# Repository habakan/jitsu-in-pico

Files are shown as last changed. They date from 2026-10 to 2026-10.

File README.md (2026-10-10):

# jitsu-in-pico

<sup>[日本語](docs/ja/README.md)</sup>

> **jitsu-in** — 実印, the seal that makes a signature binding in Japan; **pico** for the RP2350 it
> runs on.



`jitsu-in-pico` is the Raspberry Pi Pico 2 (RP2350) reference implementation for
[jitsu-in](https://github.com/habakan/jitsu-in). This repository contains the firmware, board-specific
UI and camera code, hardware documentation, and device integration checks. The reusable modules and
cross-platform examples live in jitsu-in.

Firmware stack: Pico 2 hardware, native firmware, WAMR, and jitsu-in modules

The [browser viewer](https://github.com/habakan/jitsu-in/tree/main/examples/viewer) is maintained in jitsu-in.

The device runs `parser.wasm` from jitsu-in. Its `Parser hash` screen shows the module's SHA-256;
`make check-repro` rebuilds the pinned artifacts and compares them with the recorded hashes.

| | |
|---|---|
| Modules, specifications, and cross-platform examples | [jitsu-in](https://github.com/habakan/jitsu-in) |
| Pico 2 hardware and wiring | [docs/hardware.md](docs/hardware.md), [docs/breadboard.md](docs/breadboard.md) |
| Parser ABI and host examples | [jitsu-in parser documentation](https://github.com/habakan/jitsu-in/tree/main/parser) |

Most design notes and measurements under `docs/` are in Japanese. English pages are linked from the
Japanese index at [docs/ja/README.md](docs/ja/README.md).

## Disclaimer

**This software has not been reviewed by a third party. Do not put real funds through it.**

It completes a signing round on signet. The measurements on this page come from this repository;
they do not show that anyone besides the author has tried to break it. Mainnet readiness, supported
transactions, and known limitations are listed in [docs/limitations.md](docs/limitations.md).

Found a security problem? [SECURITY.md](SECURITY.md) — **not** a public issue.

## The Pico 2 implementation

Read a seed from a SeedQR with the camera, receive a PSBT as an animated QR (UR), show it for review,
sign, and hand the signed PSBT back as a QR. The PC never holds a key or a recovery phrase — a
[signet transaction](https://mempool.space/signet/tx/de849e8c01a39fcf2aa84aaeeccb2ac8aea128086b2f4252539bcab90a0a432f)
went through that way ([verification procedure](docs/verification.md#signet-transaction)).

| Stage | Measured | |
|---|---|---|
| BIP39 seed (PBKDF2, 2048 rounds) | 0.47 s | native |
| PSBT parsing | 25 ms | **parser.wasm** (WAMR classic interpreter) |
| Checks and building the review screens | 147 ms | native |
| Signing (2 inputs, ECDSA + Schnorr) | 126 ms | native, cross-checked with embit |
| Animated QR output | 95 ms per part | reassembled byte-identical by `@ngraveio/bc-ur` |
| RAM | ~341KB of 520KB | quirc and the PSBT buffers share the heap |

Verified in this repository on RP2350 hardware, macOS hosts, and QEMU.

The firmware supports P2WPKH, P2TR key-path and P2WSH multisig of at most three keys (BIP48). BIP39
passphrase input is planned, but is not available yet.
PSBT v2 is not supported.

## Try it

### On hardware

Prebuilt firmware is on the [Releases](https://github.com/habakan/jitsu-in-pico/releases) page:
`jitsu-in-pico.uf2` for mainnet, `jitsu-in-pico-signet.uf2` for signet. Hold BOOTSEL while connecting
the Pico 2 over USB and copy the UF2 onto the drive. Building it yourself gives the same bytes
([docs/reproducible-build.md](docs/reproducible-build.md)).

Parts and wiring: [hardware](docs/hardware.md), [breadboard wiring](docs/breadboard.md). Japanese: [breadboard wiring](docs/ja/breadboard.md).

```sh
make deps-openocd                 # once, for SWD flashing (the Raspberry Pi fork of OpenOCD)
make run SECONDS=180              # flash, start listening, reset
make run TESTNET=1 SECONDS=180    # signet
```

Only a build with `TEST_SEED=1` can select the BIP39 test vector seed (the default is 0). Never put funds on it.
Known limitations and operational constraints are in [docs/limitations.md](docs/limitations.md).

## Check it yourself

```sh
make check-repro   # rebuild parser.wasm with a pinned toolchain and compare against the record
```

The device's `Parser hash` screen should match the parser hash produced by this build
([docs/reproducible-build.md](docs/reproducible-build.md)).

```sh
make check-core        # signing core vectors (71 checks)
make check-xpub        # account xpub and descriptor (official BIP84 vectors)
make check-psbt        # a full PSBT round, UR round-trip, signatures verified with embit
make check-ui          # screen construction
make check-seedqr      # SeedQR reading, with ASan
make check-qemu-psbt   # the same round on RV32, output compared with the host
make check-qemu-qr     # quirc instruction counts
make check-qr-mac      # quirc vs zxing-cpp on the same images
make check-camera-sim  # camera.pio against a Python simulator
make -C components/parts/parser test        # parser vectors (529 checks)
make -C components/parts/parser check-fuzz  # fuzzing the PSBT and UR parsers
```

Expected values come from independent implementations: embit, hashlib, `@ngraveio/bc-ur`, zxing-cpp,
Bitcoin Core. New tests are checked with mutation testing before they are trusted.

## What this repository contains

`src/` is the firmware that ships as the UF2; `bringup/` holds the other programs for the board.
Host and QEMU checks live under `tests/`.

| | | TCB |
|---|---|---|
| `components/parts/` | Pinned [jitsu-in](https://github.com/habakan/jitsu-in) submodule: reusable parser and signer modules. Their specifications and host examples are maintained in jitsu-in | **outside** |
| `components/qr/` | QR decoder ([quirc](https://github.com/habakan/quirc) submodule) | outside |
| `src/` | The firmware's entry point (`main.c`) and the pin assignment (`board_pins.h`) | inside |
| `src/drivers/` | Display (ST7789), buttons, camera (PIO + DMA). Runs only on the board | inside |
| `src/ui/` | Builds the 240x240 screens, independent of where they are shown | inside |
| `src/runtime/` | The call boundary into `parser.wasm` (every offset and length is range-checked) and the WAMR platform layer | inside |
| `bringup/` | Wiring checks and benchmarks: buttons, camera, PIO loopback, a PSBT round without UI | - |
| `tests/` | Host (`host/`), QEMU (`qemu/`) and screen (`ui/`) checks | - |
| `tools/` `docs/` | Build and verification tools, wiring diagrams, measurements, and implementation documentation |  - |

Dependencies (`third_party/`, gitignored) are cloned by `make deps`: libsecp256k1, WAMR 2.4.3,
pico-sdk 2.3.1, QR-Code-generator, the spleen font, and a RISC-V toolchain.

## Documentation

| If you want to... | Read |
|---|---|
| Understand how the device works | [System architecture](docs/architecture.md) |
| Review the parser boundary and signing path | [Signing architecture](docs/signing-architecture.md) |
| Check supported transactions and known risks | [Limitations](docs/limitations.md) |
| Rebuild and verify the published artifacts | [Reproducible build](docs/reproducible-build.md) |
| Repeat the signet transaction procedure | [Verification](docs/verification.md) |
| See performance and feasibility measurements | [Feasibility and performance](docs/feasibility.md) |
| Identify parts and wire the device | [Hardware](docs/hardware.md), [breadboard](docs/breadboard.md) |

## Contributing

Patches welcome: [CONTRIBUTING.md](CONTRIBUTING.md). Security problems go to
[SECURITY.md](SECURITY.md), never to a public issue.

## License

MIT ([LICENSE](LICENSE)). Third-party code is listed in [NOTICE](NOTICE).

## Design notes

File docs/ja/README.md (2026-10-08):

# jitsu-in-pico

<sup>[English](../../README.md)</sup>

> **jitsu-in ── 実印。** 署名に拘束力を与える印。**pico** は動作先の RP2350 から。



英語版は [README.md](../../README.md) です。

`jitsu-in-pico` は [jitsu-in](https://github.com/habakan/jitsu-in) の Raspberry Pi Pico 2（RP2350）参照実装です。
ファームウェア、基板固有の UI・カメラ処理、配線資料、実機連携の検証を置いています。
再利用モジュールと言語別の利用例は jitsu-in 側で管理しています。

## 安全上の注意

> **状態: 第三者のレビューを受けていません。本番の資金には使わないでください。**

signet で署名から送信まで一巡しました。ここに載せた数値はこのリポジトリで測ったものですが、
作者以外が攻撃を試みたことを示すものではありません。mainnet の前提や対応範囲は
[制約一覧](limitations.md)をご覧ください。

セキュリティ上の問題は [SECURITY.md](../../SECURITY.md)（英語）に従って報告してください。**公開 issue には書かないでください。**

ブラウザの [PSBT ビューア](https://github.com/habakan/jitsu-in/tree/main/examples/viewer) は jitsu-in 側で管理しています。

デバイスが使う `parser.wasm` は jitsu-in の成果物です。画面の `Parser hash` と
`make check-repro` の記録を突き合わせられます。

| | |
|---|---|
| モジュールの仕様と他環境での利用 | [jitsu-in](https://github.com/habakan/jitsu-in) |
| parser の ABI とホスト実装例 | [jitsu-in parser](https://github.com/habakan/jitsu-in/tree/main/parser)（英語） |

## Pico 2 の実装

カメラで SeedQR を読み、アニメーション QR（UR）で PSBT を受け取ります。画面で内容を確認して署名し、
署名済み PSBT を QR で返します。PC 側に鍵やシードフレーズを置かず、
[signet の取引](https://mempool.space/signet/tx/de849e8c01a39fcf2aa84aaeeccb2ac8aea128086b2f4252539bcab90a0a432f)
を送信しました（手順は [検証手順](../verification.md#signet-transaction)をご覧ください）。

| 段 | 実測 | |
|---|---|---|
| BIP39 シード（PBKDF2 2048 回） | 0.47 s | ネイティブ |
| PSBT 解析 | 25 ms | **parser.wasm**（WAMR classic interp） |
| 検査・確認画面の組み立て | 147 ms | ネイティブ |
| 署名（2 入力、ECDSA + Schnorr） | 126 ms | ネイティブ。embit で独立検証 |
| アニメーション QR 出力 | 1 パート 95 ms | `@ngraveio/bc-ur` で復元・バイト一致 |
| RAM | 約 341KB / 520KB | quirc と PSBT バッファはヒープを共有 |

このリポジトリでは、RP2350 実機、macOS のホスト、QEMU で確認しています。

## 利用方法

### 実機

ビルド済みのファームは [Releases](https://github.com/habakan/jitsu-in-pico/releases) にあります
（`jitsu-in-pico.uf2` が mainnet、`jitsu-in-pico-signet.uf2` が signet）。BOOTSEL を押しながら USB で
つなぎ、表示されたドライブに UF2 をコピーしてください。自分でビルドした場合も同じバイト列になります
（[再現可能ビルド](reproducible-build.md)をご覧ください）。

部品と論理的なピン割り当ては [hardware.md](../hardware.md)（英語）、実配線は [breadboard.md](breadboard.md)（日本語）をご覧ください。

```sh
make deps-openocd                 # 一度だけ。SWD 書き込み用（Raspberry Pi のフォーク）
make run SECONDS=180              # 書き込み → 受信開始 → リセット
make run TESTNET=1 SECONDS=180    # signet 用
```

`TEST_SEED=1` でビルドした場合だけ BIP39 のテストベクタを選べます（既定は 0）。このビルドでは資金を扱わないでください。
実機の運用上の制約は[制約一覧](limitations.md)をご覧ください。

## ビルドと検証

```sh
make check-repro   # 版を固定したツールチェーンで parser.wasm を作り直し、記録と突き合わせる
```

デバイスの `Parser hash` 画面と再現ビルドの結果が一致すれば、
**デバイス上の解析器が公開ソースからビルドされたこと**を確認できます
（[再現可能ビルド](reproducible-build.md)をご覧ください）。

```sh
make check-core        # 中核のベクタ（71 項目）
make check-xpub        # 口座 xpub とディスクリプタ（BIP84 の公式ベクタ）
make check-psbt        # PSBT 一巡 + UR の往復 + 署名を embit で独立検証
make check-ui          # 画面の組み立て
make check-seedqr      # SeedQR の読み取り（ASan 付き）
make check-qemu-psbt   # RV32 で PSBT 一巡（ホストの出力と一致するか）
make check-qemu-qr     # quirc の命令数
make check-qr-mac      # quirc と zxing-cpp の読取可否を比べる
make check-camera-sim  # camera.pio を Python のシミュレータで検証
make -C components/parts/parser test        # 解析器のベクタ（529 項目）
make -C components/parts/parser check-fuzz  # 解析器へのファジング
```

期待値は embit / hashlib / `@ngraveio/bc-ur` / zxing-cpp / Bitcoin Core で独立に作成しています。
テストを追加した場合は、ミューテーションテストで検出力を確かめています。

## 対応範囲

現在は単署名の P2WPKH / P2TR に対応しています。BIP39 パスフレーズ入力とマルチシグは今後対応予定ですが、現行ファームウェアでは使えません。マルチシグの方式は未定です。PSBT v2 には対応していません。詳しくは[制約一覧](limitations.md)をご覧ください。

## このリポジトリの内容

`src/` に UF2 として配布するファームウェア本体、`bringup/` にそれ以外の実機用プログラムがあります。
ホストと QEMU の検査は `tests/` にあります。

| | | TCB |
|---|---|---|
| `components/parts/` | [jitsu-in](https://github.com/habakan/jitsu-in) の固定 submodule。再利用する parser / signer モジュールを含む。仕様とホスト実装例の管理先は jitsu-in | **外** |
| `components/qr/` | QR デコーダ（submodule [quirc](https://github.com/habakan/quirc) の `mcu` ブランチ。FPU 無し向けに固定小数点化） | 外 |
| `src/` | ファームの入口（`main.c`）とピン割り当て（`board_pins.h`） | 内 |
| `src/drivers/` | 液晶（ST7789）、ボタン、カメラ（PIO + DMA）。実機でしか動かない | 内 |
| `src/ui/` | 240x240 の画面を組む。表示先に依存しない | 内 |
| `src/runtime/` | parser.wasm の呼び出し口（線形メモリとの出入りを範囲検証する境界）と WAMR のプラットフォーム層 | 内 |
| `bringup/` | 配線確認と計測。ボタン、カメラ、PIO ループバック、UI なしの PSBT 一巡 | - |
| `tests/` | ホスト（`host/`）、QEMU（`qemu/`）、画面（`ui/`）の検査 | - |
| `tools/` `docs/` | ビルド・検証ツール、配線図、この実装の設計と実測の記録 | - |

`third_party/`（gitignore 済み）の依存は `make deps` で clone します。libsecp256k1、WAMR 2.4.3、
pico-sdk 2.3.1、QR-Code-generator、spleen フォント、RISC-V ツールチェーンを取得します。

### 実機のファームの種類

| ターゲット | 用途 |
|---|---|
| `app` | 本体。PSBT 署名の一巡、xpub 表示、解析器ハッシュ表示 |
| `app_nolcd` | 同じ内容を UART に文字で出す（液晶なしでの回帰） |
| `psbt_bench` `qr_bench` | 時間・メモリの計測 |
| `camera_test` `pio_loopback_test` `button_test` | 配線とカメラの切り分け |

## 設計・検証資料

| 文書 | 内容 |
|---|---|
| [system architecture](../architecture.md)（英語） | 技術スタック・信頼境界・一巡・メモリ構成 |
| [signing architecture](../signing-architecture.md)（英語） | 現在の解析・署名構成と信頼境界 |
| [再現可能ビルド](reproducible-build.md) | ビルド成果物の再現方法 |
| [verification](../verification.md)（英語） | signet での送金とビルド・検証手順 |
| [Feasibility and performance measurements](../feasibility.md)（英語） | RP2350 のメモリ・速度、QR、BIP39 / BIP32、WASM / AOT の計測 |
| [hardware](../hardware.md)（英語）・[breadboard](../breadboard.md)（英語）・[breadboard](breadboard.md)（日本語） | 部品と配線、実配線図 |

計測条件と再現手順は [Feasibility and performance measurements](../feasibility.md)（英語）にまとめています。

## 外部プロジェクトへの貢献

- **WAMR**: classic interpreter の `i64.store` が 4 byte 境界を前提にしていた問題の修正を、固定した upstream commit に含めています
  （[PR #5123](https://github.com/wasm-micro-runtime/wasm-micro-runtime/pull/5123)、2026-09-30 マージ）。
  非整列アクセスを許さない CPU で発生し、QEMU では再現しません。
- **quirc**: 自前フォーク（`mcu` ブランチ）で固定小数点化と未マージのセキュリティ修正の取り込みを行い、
  UBSan とファジングを実施しています。

## 貢献

変更の送り方は [CONTRIBUTING.md](../../CONTRIBUTING.md)（英語）をご覧ください。セキュリティ上の問題は公開 issue ではなく、
[SECURITY.md](../../SECURITY.md)（英語）に従って報告してください。

## ライセンス

ライセンスは MIT です（[LICENSE](../../LICENSE)）。取り込んでいる第三者のコードは [NOTICE](../../NOTICE) をご覧ください。

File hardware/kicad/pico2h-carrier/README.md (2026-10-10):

# Pico 2 H carrier (KiCad draft)

現行の jitsu-in-pico 配線を、Pico 2 H・LCD・OV7675 のソケット接続へ移すための KiCad 下書きです。

## ファイル

- `pico2h_carrier.kicad_sch`: コネクタ単位の回路図。ネットラベルは既存の実配線に合わせています。
- `pico2h_carrier.kicad_pcb`: 58 x 38 mm・四隅1 mm面取りの外形、4つの固定穴、部品の機械領域。電気フットプリントは未配置です。
- `PicoCarrier.kicad_sym`: この設計用のコネクタシンボル。
- `sym-lib-table`: 上記シンボルライブラリのプロジェクト登録。

## コネクタ

| Ref | 対象 | フットプリント |
|---|---|---|
| J1 | Pico 2 H 左列、物理ピン1–20 | 1x20 2.54 mm female socket（B面） |
| J2 | Pico 2 H 右列、USB側から物理ピン40–21 | 1x20 2.54 mm female socket（B面） |
| J3 | M154-240240-RGB | 1x8 2.54 mm female socket |
| J4 | OV7675 / Arducam B0070 | 2x10 2.54 mm female socket（B面） |
| SW1, SW2 | 進む、承認 | 汎用6 mm THTタクトスイッチ |
| J5 | Debug Probe UART RX/GND | 1x2 2.54 mm female socket |

基板上の電気接続は回路図のネットラベルを参照してください。LCDのJ3 pin 1はGND、カメラJ4は奇数ピンが左列です。Pico右列J2 pin 1はUSB側のVBUS位置です。

## 仮レイアウト

前面（F面側）にLCDと右端の操作ボタン2個、キャリア基板の裏面（B面）にPico 2 H、背面ケースにカメラを置く積層構成です。基板の横幅はPicoの51 mm、縦幅はLCDの32 mmとカメラの30.5 mmに合わせて58 x 38 mmにしています。USB端子は左側へ向きます。LCDは前カバー、カメラは背面ケースに固定し、短いハーネスでJ3（F面）・J4（B面）へ接続します。

Rev Cの[完成・内部図](3dprint/assembly_preview.png)、[回転できる3Dビュー](3dprint/assembly.html)、[Bambu Studio用3MF・組立手順](3dprint/README.md)を用意しました。ケースは63.4 × 43.4 × 42.3 mmです。

PCB座標はケースXY座標から各2.7 mmを引いた値です。固定穴はPCB上で(3, 3)、(55, 3)、(3, 35)、(55, 35)、直径2.7 mmです。ケースを閉じるねじで、前カバー・キャリア・背面ケースを共締めします。寸法はケースと同じ寸法ファイルを使います。

`MECH_CASE`と`MECH_COMPONENTS`にそれぞれケース・電子部品の簡略VRMLを登録しています。KiCadの3Dビューで配置を参照し、内部を見たい場合は`MECH_CASE`のモデル表示を無効にしてください。VRMLの原点はPCB左上・表面です。電子部品のモデルは電気フットプリントと独立しているため、部品配置を変更した場合は参照モデルも更新します。

## 機械設計の前提

- Pico 2 H: 51 x 21 mm、ヘッダ間隔17.78 mm、2.54 mmピッチ。[Raspberry Piデータシート](https://datasheets.raspberrypi.com/pico/pico-2-datasheet.pdf)
- M154-240240-RGB: 公称基板外形43.72 x 32 mm。[秋月電子の製品ページ](https://akizukidenshi.com/catalog/g/g131019/)
- Arducam B0070: 公称基板外形30.5 x 30.5 mm、20ピン。[秋月電子の製品ページ](https://akizukidenshi.com/catalog/g/g113201/)
- TVDP01-G73BB: 6 x 6 mm、端子間ピッチ4.5 mm。[秋月電子の製品ページ](https://akizukidenshi.com/catalog/g/g109825)

公称外形と仮の実装高さに基づき、取付柱・押し子・USB開口を設けた調整用試作です。未計測のレンズ高さ、コネクタの向きと奥行き、ソケット高さは[寸法ファイル](3dprint/case_dimensions.json)に仮定を記録しています。実測後に確定してください。

## 次の作業

1. LCDとカメラの実物でヘッダ位置・固定穴・レンズ突出量を測り、基板上の配置を確定する。
2. A4に基板外形を1:1印刷し、部品とUSBケーブルの干渉を確認する。
3. KiCadでコネクタ位置と固定穴を配置し、ネットを同期して配線する。J1/J2/J4はB面配置でピン配列が反転する。
4. [3Dプリント用ケース試作](3dprint/README.md)を実物に合わせて調整し、基板を仮組みする。
5. ERC/DRCとケース寸法を確認してから製造データを出力する。

## 確認

この作業環境には KiCad がないため、KiCad上での読込確認、ERC、DRC、Gerber出力は未実施です。製造データとして発注する前にKiCadで開き、フットプリントを配置して確認してください。

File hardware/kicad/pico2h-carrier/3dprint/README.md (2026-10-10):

# Pico 2 H ケース Rev C — 調整用試作

外形 **63.4 × 43.4 × 42.3 mm**（ボタンを含む高さ43.3 mm）。キャリア基板は58 × 38 mmです。前面に液晶と操作ボタン、背面にカメラを置き、Picoはキャリア基板の裏面へ挿します。面積を小さくした代わりに部品を重ねたため、Rev Bの30.4 mmより厚くなっています。ユーザー了承のもと、未計測箇所は仮寸法で作成しています。

## 完成イメージ

- [完成・内部配置](assembly_preview.png)
- [分解図](assembly_exploded.png)
- [回して確認する3Dビュー](assembly.html)：ブラウザーで開き、「完成」「内部」「分解」を切り替えます。外部通信は不要です。
- [組立GLB](assembly.glb)：電子部品を含む閲覧用。印刷には下記の3MF/STLを使います。

画像・3Dビュー・STLは共通の形状データから生成しています。電子部品は外形を簡略化したモデルで、配線とねじ軸は省略しています。

## Bambu Studioで印刷するファイル

| ファイル | 内容 | 印刷方向 |
|---|---|---|
| [bambu_plate_01_base.3mf](bambu_plate_01_base.3mf) | 背面ケース1個（カメラ窓付き） | 外側底面がベッド |
| [bambu_plate_02_front.3mf](bambu_plate_02_front.3mf) | 前カバー1個 | 外側の画面側がベッド |
| [bambu_plate_03_small_parts.3mf](bambu_plate_03_small_parts.3mf) | カメラ裏押さえ1個、押し子2個 | 裏押さえは平置き、押し子は頭がベッド |

3MFは**mm単位の形状のみ**を含みます。3ファイルをそれぞれ別の印刷として開きます。プリンター・素材設定、サポート、G-codeは含みません。小物3個は間隔を空けて配置済みです。

プリンター本体のUSB/SDから印刷する場合、本体の一覧に出るのはスライス済みの`.gcode.3mf`だけです。この3MFをそのままコピーしても表示されません。

1. Bambu Studioで実機の機種・ノズル径を選択します。今回の想定はX2Dです。
2. 各3MFを開きます。選択肢が出た場合は形状の読み込みを選びます。
3. 倍率100%のままプレート中央に配置します。背面ケースが63.4 × 43.4 × 39.9 mmであることを確認します。
4. 素材未指定のため、最初の案はPLA・0.4 mmノズル・積層0.20 mm・壁4周・上下5層・インフィル20%です。温度とベッドは使用フィラメントのプリセットを使います。
5. 背面ケースのUSB穴上辺、押し子のつば下面はサポート対象です。プレビューで浮いた層がないか確認します。前カバーは固定柱が上向きです。外側ねじ座ぐりの橋渡しも確認してください。
6. プレートをスライスし、「プレートのスライスファイルをエクスポート」で`.gcode.3mf`を保存します。USB/SDへはこのファイルをコピーします。Bambu Studioの「印刷」から直接送ってもかまいません。
7. まず空のケースと押し子を仮組みしてから、部品を取り付けます。

X2Dの公式造形範囲（主ノズル256 × 256 × 260 mm）に収まる寸法です。[Bambu Lab公式仕様](https://blog.bambulab.com/xcellence-made-simple-bambu-lab-presents-the-x2d/)

個別STL：

- [背面ケース](pico2h_case_base.stl)
- [前カバー](pico2h_case_front.stl)
- [カメラ裏押さえ](pico2h_case_camera_retainer.stl)
- [次へ押し子](pico2h_case_button_1.stl)
- [承認押し子](pico2h_case_button_2.stl)

## どこに入るか

| 部品 | 固定・接続 |
|---|---|
| LCD M154-240240-RGB | 前面左。4つの基板穴を前カバーの柱へねじ留め。キャリア表面のJ3へ8芯ハーネス |
| 操作スイッチ2個 | キャリア表面の右端。前カバーの穴に通した押し子で操作 |
| キャリア基板 | 58 × 38 mm、四隅1 mm面取り。背面ケースの4本の柱と前カバーの柱で挟み、ケースねじで共締め |
| Pico 2 H | キャリア**裏面**の1×20ソケット2本に挿入。部品面は背面側。USBは左側の16 × 9.6 mm開口へ |
| カメラ B0070 | 背面ケースの内側。レンズを背面のØ18 mm窓へ向け、四隅の受けと裏押さえで挟んで4本のねじで固定。キャリア裏面のJ4へ20芯ハーネス。カメラ側は2×10ピンソケット（高さ8.5 mm）に短い線を付けたもの |

Picoを裏面に挿すため、KiCadではJ1/J2をB面に配置し、ピン配列が左右反転することに注意します。BOOTSELはキャリア基板を外して操作します。ブレッドボードをそのまま収納する設計ではなく、キャリア基板へ移設する前提です。

## ねじ・組立

ねじは樹脂へねじ込む試作想定です。長さは頭を除く値で、下穴径とねじ形状は試し刷りで合わせます。

| 用途 | 候補 | 数 | モデルの下穴 |
|---|---|---|---|
| ケース開閉・キャリア固定 | 呼び径2.5 × 25 mm、樹脂用タッピングねじ | 4 | Ø2.0、深さ10 mm（背面ケース側） |
| LCD固定 | M1.6 × 5 mm | 4 | Ø1.3、盲穴 |
| カメラ裏押さえ | M2 × 8 mm | 4 | Ø1.6、盲穴 |

LCD穴はØ2.0 mmなので、M2.5は使いません。LCD固定ねじは裏面から挿します。小ねじを樹脂へ直接使う箇所は、必要に応じて下穴の径・深さを調整してください。強く締め込むと柱が割れるため、基板が動かなくなる程度で止めます。

1. キャリア基板の表面にJ3・J5・スイッチ、裏面にPico用ソケットとJ4を取り付け、配線を完成させます。表面のはんだ側リードはPicoのヘッダ側へ出るため、短く切りそろえます。
2. カメラを背面ケースの四隅の受けへ置き、裏押さえをねじ留めします。カメラのハーネスを先に挿しておきます。
3. キャリア裏面へPicoを挿し、カメラのハーネスをJ4へつないでから、キャリアを背面ケースの4本の柱へ載せます。
4. 前カバーを裏返し、押し子2個を穴へ入れます。押し子は完成時にスイッチとの隙間0.2 mmを想定しています。
5. LCDを4本の柱へ固定します。ガラスと前カバーは0.3 mm離す想定です。LCDのハーネスをJ3へつなぎます。
6. 前カバーを載せ、4本のねじで前カバー・キャリア・背面ケースをまとめて固定します。
7. USBケーブルが挿せること、ボタンが戻ること、配線を挟まないことを確認します。

## 仮寸法の調整

[case_dimensions.json](case_dimensions.json)を編集して再生成します。XY座標はキャリア基板（KiCad）の座標で、ケース座標は各2.7 mm足した値です。高さ方向は背面からカメラ、Pico、キャリア、LCDの順に積み上げて自動計算します。「調整可能」は主にCAD寸法の変更・再印刷を意味し、完成品にスライド調整機構はありません。

| パラメータ | 現在値 | 実物で確認する箇所 |
|---|---|---|
| `camera.lens_height` | 3 mm（写真から2〜3 mmと推定） | **基板表面から**レンズ先端まで。裏面から測った値なら基板厚を引く |
| `camera.pcb_thickness` | 1.6 mm | カメラ基板厚 |
| `camera.lens_offset` | [15.25, 15.25] mm | 基板左上からレンズ中心 |
| `camera.rear_connector_depth` | 11 mm | 基板裏面から接続済みヘッダ・コネクタの最下面。2×10ピンソケットの短いハーネス前提。ジャンパーワイヤのメス端子は約16.5 mm＋曲げ代が要り収まらない |
| `lcd.active_origin` | [7.11, 2.14] mm | 横向き基板の左上から表示域左上。図面の向きは実物照合待ち |
| `lcd.rear_connector_depth` | 11.3 mm | LCD裏側の接続済みコネクタ |
| `pico.socket_height` / `header_height` | 8.5 / 2.5 mm | キャリア裏面からPicoまで合計11 mm |
| `pico.component_gap` | 2 mm | カメラ裏押さえとPico部品面の間隔 |
| `buttons.switch_height` | 7.3 mm | キャップを外したスイッチ上端。実物照合待ち |
| `case.fit_clearance` | 片側0.3 mm | ケースのはめ合い |

レンズ高さ・コネクタ深さを変更すると、ケースの厚みと各柱の高さも変わります。大きく変更した場合は周辺部品との干渉チェックが失敗することがあります。ヘッダの向き・XY位置、取付面、ねじ径は必要に応じて`build_case_stl.py`で変更します。ケース全体の大きな変更には配線コネクタ等の固定座標も見直してください。

カメラは四隅1.2 mm角の受けに載り、裏押さえは左右の辺1.2 mm幅を押さえます。ヘッダは上辺にあると仮定し、上辺は押さえません。その場所に部品がないか確認します。ハーネスの曲げ余裕・はんだ面・光学的な視野角はモデルに含まれていません。Ø18 mmのカメラ窓は仮値です。

## 再生成

Python 3.11の仮想環境で、リポジトリ直下から実行します。

```sh
uv venv -p 3.11 /tmp/pico-case-venv
VIRTUAL_ENV=/tmp/pico-case-venv uv pip install -r hardware/kicad/pico2h-carrier/3dprint/requirements.txt
/tmp/pico-case-venv/bin/python hardware/kicad/pico2h-carrier/3dprint/build_case_stl.py
```

STL、3MF、OpenSCAD、GLB、KiCad参照用VRML、画像、HTML、検査レポートを出力します。OpenSCADは生成結果で、寸法変更はJSON/Pythonが正本です。`part`に`base`、`lid`、`camera_retainer`、`button_1`、`button_2`を指定すると印刷向きで表示します。

KiCadの機械配置を更新する場合だけ、次を別途実行します。電気フットプリント・配線があるPCBへの自動上書きは拒否します。

```sh
/tmp/pico-case-venv/bin/python hardware/kicad/pico2h-carrier/3dprint/update_mechanical_layout.py
```

日本語画像にはmacOSのHiragino Sans GBを使用します。他のOSでは`render_case.py`の`FONT`を日本語フォントへ変更してください。

## 確認結果と残作業

- 全24パーツのメッシュについて、閉じた形状・面の向き・正の体積を確認。
- 印刷する5パーツは各1つの連結した立体。STLと3MFを再読込して形状を確認。
- 仮寸法で253組の部品の体積干渉を計算し、重なり0件。ねじ頭は対象外。[fit_report.json](fit_report.json)
- Bambu Studio 02.08.02.61の`--info`で3つの3MFを読み込み、5パーツすべて`manifold = yes`、公称寸法を確認。[読込ログ](bambu_import_check.txt)。スライス・実機印刷は未実施。
- 完成図と分解図は画像で確認。HTMLはJavaScriptの構文確認までで、ブラウザー上の操作確認は未実施。
- KiCadは固定穴・外形・機械領域・3D参照を更新済み。**電気フットプリント配置・配線・ERC/DRCは未完了**。KiCad本体がないためネイティブ読込は未確認です。

寸法根拠：[Pico 2](https://datasheets.raspberrypi.com/pico/pico-2-datasheet.pdf)、[LCD図面](https://akizukidenshi.com/goodsaffix/M154-240240-RGB-8.pdf)、[B0070製品情報](https://akizukidenshi.com/catalog/g/g113201/)、[スイッチ図面](https://akizukidenshi.com/goodsaffix/TVDP01-G73BB.pdf)。レンズ・コネクタ等の仮定はJSONと検査レポートにも記録しています。

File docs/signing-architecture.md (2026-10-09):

# Signing architecture: isolate parsing in WASM, keep keys and signing native

This is the current implementation. `parser.wasm` handles UR reassembly and PSBT parsing without
access to keys. Native code validates the fixed-size `Plan`, derives and checks keys, builds the
review screens, and signs. QR image decoding also runs natively and remains in the trusted computing
base.

## 1. The point

Keep the key outside the module that parses untrusted transaction data. If `parser.wasm` is
compromised, it cannot read the key from its linear memory.

## 2. What this defends against, and what it does not

| attack | current design |
|---|---|
| a crafted PSBT or UR takes over the parser and reads the key | defended. The key never enters the WASM linear memory |
| a compromised parser shows A on screen and signs B | defended. What is displayed and what goes into the sighash are built natively from the same struct (§5) |
| a compromised parser honestly displays a transaction the user should not accept | not defended. That is what the user's confirmation is for |
| a compromised parser corrupts the output PSBT | not defended. A signature commits to the transaction, so a corrupted PSBT is merely invalid — denial of service |
| the QR decoder (quirc) is taken over | not defended. quirc stays native and stays in the TCB (§7) |
| the SeedQR parser is taken over | out of scope, because that parser is not in WASM (§4) |

## 3. The shape of it

```
Camera ─> quirc (native) ─> QR payload bytes
                                 │
                                 ▼
             ┌──────── parser.wasm (no keys) ───────┐
             │ UR / BBQr reassembly, CBOR, PSBT     │
             │ parsing, then a fixed-length Plan    │
             └───────────────┬──────────────────────┘
                             │ the host copies the plan and non_witness_utxo, with checks
                             ▼
             ┌──────── signing core (native) ───────┐
             │ check the Plan, derive keys, confirm  │
             │ ownership, build the display, sighash,│
             │ sign                                  │
             └───────────────┬──────────────────────┘
                             │ the host writes back the signatures (plan_sig_t)
                             ▼
             parser.wasm: insert partial_sig into the original PSBT and serialize
                             │
                             ▼
                     qrcodegen (native) ─> LCD
```

parser.wasm has no imports at all. Everything crosses through buffers it exports, which the host reads
and writes. The host checks every address and length it returns against the bounds of the linear memory
with `wasm_runtime_validate_app_addr` before copying anything.

## 4. Who does what

| what | where | why |
|---|---|---|
| decoding the QR image (quirc) | native | over ten seconds per frame in WASM ([QR feasibility measurements](feasibility.md#qr-decoding-on-the-rp2350)) |
| UR / BBQr reassembly, CBOR, PSBT parsing | parser.wasm | the most complex parsing of untrusted input, and light because no crypto is involved |
| parsing a SeedQR or typed words | native | the input is the secret itself, so putting it in WASM would defeat the isolation |
| checking the Plan, deriving keys, confirming ownership, sighash, signing | native | it touches keys |
| building address strings (bech32 / base58) | native | the Plan carries only the scriptPubKey's bytes, so the parser cannot fake a string |
| the wording and numbers on the review screens | native | so that what is shown and what is signed come from the same struct |
| serializing the signed PSBT | parser.wasm | a signature commits to the transaction, so a compromise here cannot forge anything |

## 5. The core invariant

**What is displayed and what goes into the sighash are built natively, from the same `plan_t`.**
If parser.wasm emits a Plan that differs from the original PSBT, then that Plan is what the user sees
and that Plan is what gets signed. The native side does not need to establish that the Plan is faithful
to the PSBT. It only establishes two things:

1. that the Plan is internally consistent (§6)
2. that nothing bad happens if a value the user is not shown, such as an input amount, is a lie
   (§6, items 4 and 5)

## 6. What the native side checks

1. **Form:** record counts and lengths within their limits, unused fields zero, no reserved values.
   Nothing variable-length is parsed
2. **Inputs to be signed:** derive the key at the path the Plan gives and confirm the public key
   produces `witness_utxo.scriptPubKey` — `0014 || HASH160(pub)` for P2WPKH, the x-only key after the
   BIP86 tweak for P2TR. An input that does not match is not signed
3. **Deciding what is change:** an output's `key` is treated as a hint only. The native side re-derives
   the script on the same account's change chain (`.../1/i`, with a limit on `i`) and only calls it
   change when it matches
4. **The fee:** total input minus total output, computed natively. Overflow and negative values are
   refused
5. **Guarding against a lie about an input's amount:**
   - Taproot (BIP341) commits the sighash to every input's amount and scriptPubKey, so a signature made
     with a false amount is simply invalid
   - SegWit v0 (BIP143) commits only to the amount of the input being signed. That is what makes the
     2020 fee attack work: get the same input signed twice with different amounts. The countermeasure
     is to require `non_witness_utxo` in the multi-input case (§8, item 1)
6. **sighash type:** only `SIGHASH_ALL` and Taproot's `SIGHASH_DEFAULT` are accepted; all other types
   are rejected
7. **Network:** mainnet or testnet is decided by the native configuration, not by the Plan

## 7. What risk remains

- **quirc remains a parser of untrusted input inside the TCB.** It is fuzzed, but remains part of the
  trusted computing base because decoding in WASM is too slow
- **The code that reads the Plan also reads untrusted input natively.** Restricted to fixed-length
  records and kept to around a hundred lines
- **An input that makes parser.wasm run indefinitely.** WAMR runs without an instruction limit, so the
  call can block the UI until the device is reset
- **A vulnerability in WAMR itself.** If the linear memory's bounds checks can be broken, the isolation
  no longer holds. The WAMR interpreter remains part of the TCB

## 8. Current transaction support and constraints

1. **`non_witness_utxo` for SegWit v0 inputs:** required for every input when a SegWit v0 input is to
   be signed and there are two or more inputs. With a single input it is unnecessary, since a signature
   made with a false amount is merely invalid. The minimal native tx parser
   (`components/parts/parser/src/tx.c`, shared with jitsu-in) checks the txid, vout, amount and script
2. **First targets:** P2WPKH (BIP84) and P2TR (BIP86, no script tree)
3. **parser.wasm runtime:** the interpreter. Measured on RV32: 2.7M instructions
   to parse a PSBT and 40k to insert the signatures (§10), which is plenty
4. **Multisig:** not implemented. Script formats and nonce handling remain undecided.

## 9. Plan layout

The C struct is shared as is, with its size and offsets nailed down by `_Static_assert`. wasm32 and
rv32 are both little-endian ILP32, so the layout agrees. The native side copies it once, then checks it.

```c
#define PLAN_MAX_INPUTS  16
#define PLAN_MAX_OUTPUTS 16
#define PLAN_MAX_SPK     83   /* the standard OP_RETURN limit; P2TR and P2WSH need 34 */
#define PLAN_MAX_DEPTH   8

typedef struct {
    uint8_t  len;
    uint8_t  bytes[PLAN_MAX_SPK];
} plan_script_t;

typedef struct {
    uint8_t  depth;
    uint32_t fingerprint;
    uint32_t path[PLAN_MAX_DEPTH];
} plan_keypath_t;

typedef struct {
    uint8_t  prev_txid[32];
    uint32_t prev_vout;
    uint32_t sequence;
    uint64_t amount;            /* witness_utxo */
    plan_script_t spk;          /* witness_utxo */
    plan_keypath_t key;         /* depth = 0 for an input we will not sign */
    uint8_t  sighash_type;
} plan_input_t;

typedef struct {
    uint64_t amount;
    plan_script_t spk;
    plan_keypath_t key;         /* a change candidate; the native side re-derives to confirm */
} plan_output_t;

typedef struct {
    uint32_t magic, version;
    int32_t  tx_version;
    uint32_t locktime;
    uint8_t  n_inputs, n_outputs;
    plan_input_t  inputs[PLAN_MAX_INPUTS];
    plan_output_t outputs[PLAN_MAX_OUTPUTS];
} plan_t;
```

- The settled version is `components/parts/parser/include/plan.h`, on the jitsu-in side, with
  `_Static_assert` fixing the size and the offsets
- At 16 inputs and 16 outputs it is 5,016 bytes: 176 per input, 136 per output. Barely a dent in RAM
- These limits are part of the current parser ABI.
- `non_witness_utxo` crosses in a buffer of its own rather than in the Plan, with the same limit as the
  whole PSBT

## 10. Current implementation

The native core is implemented in `components/parts/signer/` (`make check-core`, `make check-qemu-core`).

| file | what it holds |
|---|---|
| `components/parts/signer/core.c` | the checks from §6 (`core_review`), the display model (`core_display`) and signing (`core_sign`). It records the SHA-256 of the reviewed plan and refuses to display or sign anything that does not match |
| `components/parts/signer/address.c` | addresses from a scriptPubKey: base58check for P2PKH and P2SH, bech32 for witness v0, bech32m for v1-v16. Nothing is produced for a non-standard script |
| `components/parts/signer/sighash.c` | BIP143 (P2WPKH, SIGHASH_ALL) and BIP341 key path, all seven hash types |
| `components/parts/parser/src/tx.c` | the minimal tx parser, shared with jitsu-in. Refuses non-minimal varints and trailing bytes; the txid is computed without the witness |
| `components/parts/signer/bip32.c` | BIP32 derivation |
| `components/parts/parser/src/sha256.c`, `components/parts/signer/ripemd160.c`, `sha512.c` | the hashes. Secrets are cleared through `components/parts/signer/wipe.h`, via a volatile pointer, so the optimiser cannot remove it |

What `core_review` actually does, making §6 concrete:

- An input that does not claim our fingerprint is not signed; its amount is used only for the fee. One
  that does claim it, but whose key does not produce its script, rejects the whole plan
- sighash types: `ALL` only for P2WPKH, `DEFAULT` and `ALL` only for P2TR
- An output counts as ours at `m/84'|86' / coin' / account' / {0|1} / i` — coin from the network
  setting, `i < 100000` — on the same account as the inputs being signed, and only when the script
  matches. Chain 1 is change, chain 0 is a self-transfer, which is what SeedSigner confirms as such.
  Anything else is external
- Every string on the review screens is built natively from the plan's bytes. A script that has no
  address is shown as the data for an OP_RETURN, or as the whole script in hex otherwise. The amount
  spent (`spend`) is the total of the external outputs

Tests: 71 checks, passing on both the Mac and RV32:

- BIP143's P2WPKH example: the sighash and the RFC6979 signature (DER) match the document
- The seven key-path cases from BIP341's wallet test vectors: sighash and Schnorr signature match, for
  every hash type
- BIP84 and BIP86: with the key derived from `abandon ... about`, review and signing pass and the
  signature verifies. The expected scripts are computed independently with embit and cross-checked
  against the values in BIP86 (`tools/generate/gen_core_vectors.py`)
- Addresses: BIP350's eight valid vectors; that invalid program lengths (1 and 41 bytes, and 16 and 21
  at v0) produce nothing; base58check, with embit for the expected values; the known addresses from
  BIP84 and BIP86
- Attack scenarios: swapping the plan after review, for both display and sign; fake change; a
  self-transfer; the index limit; change on another account; a key that does not match its script; a
  sighash type we do not allow; a non-zero unused field; outputs exceeding inputs; and the fee attack
  with no previous transaction, with a false amount, with the wrong vout and with the wrong txid
- Five deliberate breakages — BIP143's hash type, BIP341's spend_type, the fee-attack check, bech32m's
  constant, base58's leading zeros — were each confirmed to make a test fail

### parser.wasm (`components/parts/parser/src/psbt.c`, the [jitsu-in](https://github.com/habakan/jitsu-in) submodule)

- Turns a PSBT v0 (BIP174) into a `plan_t`, and inserts the natively produced signatures just before
  the end of each input map, leaving every other byte as it was
- The `.wasm` is 15,570 bytes and has no imports. It holds the input and output buffers
  (`PSBT_MAX` 32KB), so the linear memory is two pages
- Fields it interprets are checked strictly: duplicate keys, key and value lengths per type,
  v2-only fields, scriptSig and witness in the unsigned tx, the `non_witness_utxo`'s txid against
  `witness_utxo`, and trailing bytes
- Fields it does not interpret, MuSig2's among them, pass through untouched. It does not check whether
  a public key is on the curve, because the native side never uses the PSBT's public keys — it derives
  its own
- The only candidates for our keys are derivations matching the master fingerprint the host supplied,
  which is not a secret. Inputs already finalized or signed, and P2TR with a script tree, are not signed
- ECDSA uses the same low-R grinding as Bitcoin Core (`components/parts/signer/core.c`), so the signatures
  match embit's byte for byte

Verification (`make check-psbt`, `make check-qemu-psbt`):

- Six PSBTs built with embit for our own seed — P2WPKH with one and two inputs, P2TR with two, a mix,
  one including someone else's input, and two inputs with no `non_witness_utxo` — go through a full
  round, and the signed PSBT is verified independently with embit (`tests/host/check_signed_psbt.py`). The
  ECDSA signatures match embit's own byte for byte, and the Schnorr ones verify against embit's BIP341
  sighash. The two-input case with no `non_witness_utxo` is refused with `CORE_ERR_PREVTX_MISSING`
- Against Bitcoin Core's `test/functional/data/rpc_psbt.json` — 84 invalid and 48 valid, two of which
  have corrupt base64 and are excluded — there are no traps. Every invalid one is refused except the 15
  with MuSig2 fields. Of the valid ones 31 are accepted; the 14 PSBT v2 cases, two with no utxo and one
  with no inputs are refused (`make check-parser` in jitsu-in, `make check-parser` here)
- A full round on a mixed PSBT under RV32 (QEMU): parse 2.72M, review 17.1M, sign 14.5M, finalize 0.04M
  instructions. The signed PSBT is byte-identical between the Mac and RV32

### Bitcoin Core as the oracle (2026-10-04)

Core has no WASM target. Its PSBT code does compile to wasm32, though — measured, not assumed, with
our pinned wasi-sdk 34 (2026-10-04):

| | code | data | total | imports |
|---|---:|---:|---:|---:|
| `parser.wasm` | 13,562 | 1,369 | 15,570 | **0** |
| C++ with no STL and no exceptions | 7,658 | 0 | 8,022 | 3 |
| the same plus `string`, `vector`, `map` | 21,343 | 2,459 | 24,316 | 4 |
| `psbt.cpp` and 17 files of its closure | 103,219 | 9,746 | 114,549 | 17 |

Stripped and `wasm-opt -Oz`'d, it is 114,549 bytes, about 7x ours — not the 2.8 MB an unstripped link
reports, 93% of which is debug info. Where the difference comes from: a C++ floor of 7.7KB for
wasi-libc's startup and malloc, 13.7KB more for the STL templates and their allocator, and the rest
Core's own breadth — every script type, finalize, combine, miniscript, against our P2WPKH and P2TR key
path. Template instantiation in `serialize.h`, dynamic allocation and per-function unwind tables are
what grow it; our 13.5KB is barely above the bare C++ floor because there is none of that.

Two things still rule it out.

**Core's script code requires C++ exceptions**, and they do not link. `-fno-exceptions` fails to
compile (`script/script.h:248: cannot use 'throw' with exceptions disabled`), and with them enabled
wasi-sdk 34's prebuilt `libc++abi.a` leaves `_Unwind_RaiseException` and `__cpp_exception` undefined.
The 114,549-byte figure above only links because `--allow-undefined` turns those into imports, so it
is a module that would not run. Closing it means building libc++ from source, which gives up the
pinned official tarball the reproducible build rests on. In wasm, exceptions also mean the
exception-handling proposal, which is not one of Lime1's seven features, so the link-time gate rejects
it anyway — exactly what that gate is for. Clang 23 emits the new form (`try_table`, `exnref`) while
our pinned WAMR implements the old one (`TRY`, `CATCH`, `DELEGATE`), so the two do not even meet.

**On the device it does not fit regardless.** The classic interpreter rewrites bytecode as it loads,
so the module has to sit in writable RAM, and the RP2350 has 520KB in total for everything.

So this could run in a browser, where none of that binds, but never on the device. Patching out the
throws would change the picture — and would mean forking Core, at which point "verifiably the same
code as Core" is the thing that has been lost.

What we do take from Core verbatim is the part where being identical matters most —
**libsecp256k1, pinned to a commit**. Everything else is ours: PSBT parsing, sighash, BIP32, base58
and bech32, the hashes.

So rather than sharing Core's code, we require Core's answers (`make check-core-diff`).

| what is compared | how |
|---|---|
| the parse | `decodepsbt` against the `plan_t` parser.wasm built: version, locktime, and every txid, vout, sequence, amount, scriptPubKey, derivation path and master fingerprint |
| the fee | `decodepsbt`'s fee against `core_review`'s |
| **the signatures** | `walletprocesspsbt`'s against ours, **byte for byte** |

The third is only possible because both sides are deterministic: Core and this signer both grind for a
low R in ECDSA, and both pass a zero `aux_rand` for Schnorr. The same key over the same PSBT therefore
has exactly one right answer, and Core's is the authoritative one.

Measured: **39 PSBTs agree on the parse** — Core's own `rpc_psbt.json` valid cases plus our vectors —
and **8 signatures across 5 PSBTs are byte-identical**, ECDSA and Schnorr alike. Deliberately breaking
the low-R grinding makes two of them differ and the target fail. Notably one case still matched by
chance, because its first attempt already had a low R, so a single test case would have missed it.

Two things this does **not** claim. It does not show we share code with Core; it shows we give the same
answers, which is the part a user actually depends on. And `decodepsbt` describes what is in the file
while `plan_t` is an instruction to the signer, so the two are not the same kind of object: an input we
will not sign carries `sighash_type = 0` whatever the file says, and `core_review` rejects a plan that
breaks that (`core.c:93`). The comparison only requires agreement where both describe the same thing.

### Reassembling a UR, the animated QR

UR (BCR-2020-005) reassembly went into parser.wasm (in jitsu-in). Reassembling a fountain code is
also processing of untrusted input, so it belongs inside the sandbox.

- `parser_ur_reset`, `parser_ur_receive(len)`, `parser_ur_progress`. On completion the PSBT sits in the
  input buffer, ready for `parser_parse`. The accepted types are `crypto-psbt` and `psbt`
- The Xoshiro256**, the alias sampler and the shuffle that decide which fragments were mixed all match
  the expected values in Blockchain Commons' bc-ur tests: 1,148 checks, run natively under ASan and
  UBSan. Dropping one part and feeding the rest in reverse completes at the same 16 parts as the
  reference decoder, @ngraveio/bc-ur 1.1.13
- URs of our own PSBTs made with the reference encoder (`crypto-psbt` and `psbt`, fragments of 60, 150
  and 5000 bytes), fed in with one pure part in three dropped, come back as the original PSBT
- RV32 (QEMU): a mixed PSBT across 19 parts of 60-byte fragments costs 22.16M instructions in total and
  at most 4.23M for one part, which is 30 to 40ms at 150MHz. Signing the reassembled PSBT gives bytes
  identical to signing the binary one
- The `.wasm` reached 14KB, still with no imports. The linear memory in use (`__heap_base`) grew from
  88KB to 158KB, then came back to 132KB by removing the working arrays for the sampling and the
  shuffle. The order of computation did not change, so agreement with the reference still holds. WAMR's
  pool peaks at 147KB under QEMU, and the device application gives it 160KB

### Handing the signed PSBT back as an animated QR

- Encoding to a UR also lives in parser.wasm (`parser_ur_encode_start`, `parser_ur_encode_next`). It is
  formatting output for an untrusted wallet, so it has no bearing on the safety of the signature and can
  sit outside the TCB. Part for part it matches the reference encoder, @ngraveio/bc-ur, and it matches
  bc-ur's examples character for character (tested in jitsu-in)
- One part is 120 bytes, about 300 characters, which lands around QR v8, shown on the 240 px LCD at
  4 px per module (`ui_qr_render_line`, with a four-module quiet zone). Mixed parts keep coming after
  the pure ones, so a wallet that misses one can still reassemble
- Verification: reading the signed PSBT's UR back gives identical bytes, and rendering the LCD's QR
  screen to an image and reading it with zxing-cpp gives the part's string (`make check-psbt`)
- On the hardware (2026-10-01): a phone's QR reader reads the animated QR off the LCD. At 100 bytes per
  part it fits QR v8, 49 modules, which is 4 px per module on a 240 px LCD. At 120 bytes it became v9,
  the scale dropped to 3 px, and it would not read — so **the constraint is keeping the part small
  enough that the version does not go up**. The display cycles only the pure parts at 500ms, which lets
  a receiver that ignores mixed parts still complete, and brings a missed part round again. The output
  decodes with `@ngraveio/bc-ur` 1.1.13, the reference implementation BlueWallet and others use:
  complete in 10 frames, byte-identical to the PSBT. Dropping three frames still reassembles, from the
  mixed parts
- RV32 (QEMU): per frame, about 1.5M instructions to encode the UR and at most about 8M to build the QR.
  At 150MHz that is 60 to 95ms, inside a 250ms animation interval
- The device application: 164KB of flash, 297KB of RAM, with 160KB of that the WAMR pool, which peaks at
  149KB under QEMU. Measurements are in §11

## 11. Measured on the hardware (Pico 2 H, 150MHz, 2026-09-25)

`bringup/psbt_bench.c`, with no screen and no buttons, runs a built-in test PSBT — two
inputs, three outputs, P2WPKH and P2TR mixed — through a full round. The core is native in both
columns; only how parser.wasm executes differs.

| step | where | classic interp | AOT, expanded into RAM |
|---|---|---|---|
| runtime init | - | 22.6 ms | 10.2 ms |
| seed (PBKDF2 and master) | native | 469 ms | 470 ms |
| parsing the PSBT | **wasm** | 26.0 ms | **1.3 ms** |
| checking and building the display | native | 155 ms | 142 ms |
| signing, two inputs | native | 133 ms | 123 ms |
| finalize, inserting the signatures | **wasm** | 0.93 ms | **0.16 ms** |
| UR encoding and QR building, 8 parts | wasm + native | 797 ms, worst 95 ms per part | 689 ms, worst 86 ms per part |
| WAMR pool peak | - | 152,792 B | 196,808 B |
| flash / RAM | - | 158KB / 370KB | 179KB / 357KB |

- Both produce a signed PSBT matching the host's (`build/psbt/own_mixed_nwu.signed`). With the
  interpreter the pool peak matches QEMU exactly
- **Looking only at the wasm, AOT is twenty times faster**: parsing 26.0 to 1.3 ms, finalize 0.93 to
  0.16 ms
- **But across the whole round it is 806 ms against 746 ms, a difference of 8%.** In the current design the
  parser is light, and the time goes on the native checking and signing and on the seed
- So **the interpreter is enough for parser.wasm**. AOT costs 44KB of RAM and 21KB of flash
  and puts wamrc and LLVM in the TCB, which that 8% does not justify
- The native side — 142 to 155 ms checking, 123 to 133 ms signing — came out as the QEMU instruction
  counts predicted, 148 ms and 125 ms. The interpreter build is 9% slower because linking differently
  changes how the XIP cache happens to hit
- A QR part takes 86 to 95 ms, inside a 250 ms animation interval, as expected

## 12. A full round on the hardware (2026-10-02)

Reading from the camera, signing, and handing it back as an animated QR all work on the hardware.

```
camera: ready
seed 469365 us, fingerprint 73c5da0a
scan: 7 parts, psbt 744 bytes      <- reassembled from 7 of 8 parts; a mixed part filled the gap
parse 24078 us, pool highmark 152792
review 131043 us
sign -> signed PSBT -> 10 UR parts out
```

- While reading, the camera image goes to the panel with how many of how many parts, and what is being
  detected (`no QR in view` / `QR found, cannot read`), on the first line. Without being able to aim it
  is not usable
- `tools/psbt/show_ur.py` turns the UR's parts into an animated GIF, so a PC screen can present it to the
  camera. The UR for an unsigned PSBT comes from `psbt_host bin2ur`
- The menu is `Scan PSBT`, `Sign test PSBT` (only in a TEST_SEED build) and `Lock`

## 13. SeedQR (2026-10-02)

The key can be entered through the camera too. Read on the hardware, the fingerprint matched the test
seed's.

- **It carries the secret itself, so it is handled natively, inside the TCB, and never goes through the
  parser.** This is where it differs from a PSBT
- **The BIP39 checksum is always verified.** A single character misread is refused
- Both a standard SeedQR, 48 or 96 digits of four-digit word indices, and a CompactSeedQR, 16 or 32
  bytes of entropy
- The word list comes from `components/parts`, generated only after checking the official
  `english.txt` against its SHA-256 (16KB of flash)
- The mnemonic and the seed are cleared with `wipe()` once finished with
- Tested by `make check-seedqr`, 68 checks: 10 confirmed independently with embit, and the nine
  published SeedQR vectors read and written, as digits and as compact bytes. **Build it with ASan**:
  an input like index 2048, whose low 11 bits equal a valid value, passes the checksum and reads past
  the end of the word list, so watching only the return value hides a missing range check

## 14. Interoperating with a real wallet (2026-10-02)

Connected to Sparrow on signet, a transaction signed on the hardware went out to the network.

| step | what happened |
|---|---|
| the key | a SeedQR made from 12 words generated in Sparrow, read with the device's camera. The fingerprints matched |
| the PSBT | Sparrow's **Show QR**, a UR animated QR, read with the device's camera |
| review | destination, amount and fee on the panel. Outputs to ourselves showed as `Self-transfer` and change as `Change` |
| signing | on the device, natively |
| back again | the animated QR on the device's panel taken in with Sparrow's **Scan QR**, then broadcast |

The result: [`d22944da...`](https://mempool.space/signet/tx/d22944daeb353fc4e02012f080c632ddc8973b0395442f59d55e091a78610253),
one input and two outputs, 140 vbytes, a fee of 136 sats. **Confirmed in block 324603.** The witness
carried its two elements and a node verified the signature and accepted it.

- A `TESTNET=1` build targets signet and testnet: `m/84'/1'/0'`, with `tb1...` addresses.
  `core_review` has always checked the derivation path's coin type against the network
- Set Sparrow's **Preferences → Appearance → QR Density** to `Low`. The device's camera, QVGA plus
  quirc, reads reliably up to about v8, 49 modules
- **Not for mainnet yet.** With a Debug Probe attached the RAM can be read, and there is no case and no
  PIN. Using this for real needs the SWD detached and a third-party review; the xpub export was
  finished on 2026-10-03

## 15. Key handling and signing safeguards

**With a Debug Probe attached the RAM can be read, which exposes the seed.** No design choice prevents
that, so it is handled by how the device is used, and by leaving fewer traces.

1. **Build with `TEST_SEED=0`.** That is now the default (`make build/rp2350/app.elf`). It used to be
   hardcoded to 1 in CMakeLists, which meant any build could select the test seed. For development,
   say so explicitly: `make run TEST_SEED=1 TESTNET=1`
2. **Physically remove the Debug Probe.** Unplug the cable after flashing. The UART log goes with it
3. **Finish with `Lock (wipe seed)`.** Always, when done. `core_unload` zeroes the key

Traces of the seed that were being left behind now get cleared too.

| what was left | what now happens |
|---|---|
| `quirc_code` / `quirc_data`, static, holding the SeedQR's 48 digits verbatim | `wipe` once read |
| the captured camera frame, with the SeedQR in it | `wipe` before release |
| the mnemonic and the seed, already cleared | unchanged |

What goes to the UART is the fingerprint and some timings — never the seed or the mnemonic. Confirmed.

#### Measured (2026-10-04)

What had been written as an assumption was checked on the hardware. `tools/security/ram_scan.py` and OpenOCD
dump all 520KB of SRAM, and the values derived from the test seed were searched for in it.

| route | result |
|---|---|
| **BOOTSEL and picotool** | **nothing readable.** The SRAM was 100% zero: the bootrom clears it |
| **SWD, with the key loaded** | **the master private key and chain code are readable**, at `0x2000c1ec` and `0x2000c20c` |
| **SWD, after `Lock`** | **those same addresses are zeroed**, with the application still running |

Nothing but the key was left behind, even before pressing `Lock`.

| searched for | found |
|---|---|
| the mnemonic, 12 words | nothing |
| the BIP39 seed, 64 bytes | nothing |
| the SeedQR payload and the camera frame | nothing; that clearing went in the same day |
| the account private key | nothing; the derivation is transient |
| **the master key and chain code** | **present**, held deliberately because signing needs them |

As a control, the application's name string and the magic of the `parser.wasm` expanded into RAM were
both confirmed present in the same dump — which is how we know the dump is real.

#### Searching without knowing the value: a structural scan

The check above searches for **known values**, so it cannot find a remnant nobody thought of. So
`tools/security/ram_keys.py` takes every 32-byte window as if it were a private key and asks whether the public
key it derives is one we recognise. **That finds a key by its properties, without knowing its value.**

The one that matters most is **a signature's nonce, k**. If 32 bytes satisfying `k*G == R` for a
published signature's R are still in RAM, that nonce and that signature together recover the private
key. It is the most dangerous remnant there is.

| scan | result |
|---|---|
| with the key loaded, 330k windows against 83 keys | **only the master key.** No intermediate child key survives |
| after `Lock` | **nothing** |
| **the ECDSA nonce, immediately after signing** | **not present** |
| **the Schnorr nonce, immediately after signing** | **not present** |
| the child keys used to sign, 20 receive and 20 change | not present |

So being safe after the signature has gone out is measured, not assumed. What makes it hold is
`sign_input` wiping the child key it derived, and libsecp256k1 clearing the nonce internally.

**The conclusion.** What stays in RAM is the minimum signing needs, and the only route that reads it is
SWD. So two things close it: **physically unplugging the Probe** and **pressing `Lock`**. Both are
backed by measurement.

### Defences around signing

This looked at first like one question — whether to put good randomness in aux — but reading what other
implementations do showed **three independent ones**.

| | does randomness quality matter | protects against | here |
|---|---|---|---|
| BIP340's aux | yes, for it to do anything | an extra layer against faults and side channels | **zero, deterministic** |
| verifying after signing | no | fault injection | **added** |
| blinding the context | **no** | power analysis | **added** |

**aux is zero.** BIP340 states outright that ordinary security, side channels aside, does not depend on
the quality of the RNG at signing time — and in practice Bitcoin Core
(`// Use uint256{} as aux_rnd for now.`), Trezor (NULL at every call), Blockstream Jade (anti-exfil is
ECDSA-only and does not cover taproot), SeedSigner and embit (no aux argument in the API) and BDK
(explicitly choosing `sign_schnorr_no_aux_rand`) are all deterministic. The only one found passing
randomness was Coldcard's edge branch.

Being deterministic means **the same PSBT always gives the same signature**, so the browser's
`bitcoin-signer.wasm` can reproduce the device's output bit for bit. The ECDSA side is already
deterministic through low-R grinding, so the whole device agrees.

**In its place, the two defences other implementations do use went in.**

- **Verifying after signing**: check our own signature before letting it out. A glitched signature set
  next to a correct one can recover the key, which is differential fault analysis; not emitting it
  withholds the material. Core, BDK, btcd and BIP340's step 15 all do the same
- **Blinding the context**: call `secp256k1_context_randomize` before signing, so the intermediate
  values of every computation touching the key differ each time. Averaging power traces over repeated
  runs stops working. **The quality of this randomness does not matter**, so `pico_rand` is enough: a
  predictable value costs nothing in security, it just stops helping. Trezor calls it twice per
  signature, Coldcard once per session, Core at startup

The cost is 2,552 bytes of flash. **Deterministic nonces become unsafe with multisig** — BIP340 says so
— which is when aux has to be revisited. There is a comment in the code saying as much.

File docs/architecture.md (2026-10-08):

# How the system is put together

The current device architecture. Detailed checks and the reason for the parser boundary are in
[signing-architecture.md](signing-architecture.md).

The firmware stack at a glance:

Firmware stack: Pico 2 hardware, native firmware, WAMR, and jitsu-in modules

## 1. The trust boundary

UR and PSBT data are parsed inside a WASM module that holds no keys. Camera frames are decoded by
native quirc, which remains in the trusted computing base. The keys and signing stay native, and the
parser and signer communicate through a fixed-length record.

```mermaid
flowchart TB
    subgraph untrusted["untrusted (an attacker chooses these bytes)"]
        qr["animated QR / SeedQR"]
        wallet["the wallet on a PC"]
    end

    subgraph device["the device (RP2350, no OS)"]
        subgraph sandbox["WASM sandbox (holds no keys)"]
            parser["parser.wasm<br/>UR reassembly, CBOR, PSBT parsing, building the Plan<br/>then taking signatures back and encoding a UR"]
        end

        subgraph tcb["the TCB (native)"]
            boundary["host ABI<br/>copies, with every address checked against the linear memory"]
            core["signing core<br/>re-check the Plan, BIP32 derivation, confirm ownership,<br/>build what is displayed, sighash, sign"]
            seedqr["SeedQR parsing<br/>verifies the BIP39 checksum"]
            ui["UI<br/>review screens, menu, drawing QRs"]
        end

        subgraph drivers["peripherals (native)"]
            cam["camera<br/>PIO + DMA"]
            quirc["quirc<br/>QR decoding"]
            lcd["ST7789 panel"]
            btn["buttons"]
        end
    end

    qr --> cam --> quirc
    quirc -->|"the QR's string"| boundary
    quirc -->|"SeedQR"| seedqr
    seedqr -->|"64-byte seed"| core
    boundary <--> parser
    boundary <-->|"Plan / signatures"| core
    core --> ui --> lcd
    btn --> ui
    ui -->|"approval"| core
    boundary -->|"the signed UR"| lcd
    lcd -.->|"read with a camera"| wallet
    wallet -.->|"unsigned PSBT"| qr
```

What the boundary is actually enforcing:

- `parser.wasm` has **no imports at all**. No clock, no allocation, no network
- The host checks every address and length `parser.wasm` returns with
  `wasm_runtime_validate_app_addr` before copying anything
- What crosses is one fixed 5,016-byte `plan_t`, with its layout nailed down by `_Static_assert`
- **The native side re-checks the Plan.** If the parser lies, key derivation and the ownership check
  happen independently on the native side anyway
- That what was shown is what gets signed is enforced by `core_sign` requiring the SHA-256 of the Plan
  to match the one `core_review` was given

## 2. One signing round

```mermaid
sequenceDiagram
    participant W as the wallet on a PC
    participant C as camera + quirc
    participant P as parser.wasm
    participant K as signing core
    participant L as panel + buttons

    Note over K: read a SeedQR and put the key in RAM (0.47s)
    W->>C: shows the unsigned PSBT as an animated QR
    loop until the parts are complete (measured: 7 of 8 sufficed)
        C->>P: one UR part
        P-->>L: progress, "3/8 parts"
    end
    P->>K: the Plan (fixed length) and the previous transactions
    Note over K: re-check, derive, confirm ownership (147ms)
    K->>L: five review screens: where, how much, the fee
    L->>K: approval, after every screen has been seen
    Note over K: sign (126ms for two inputs)
    K->>P: the signatures
    P->>L: the signed PSBT as UR parts
    L-->>W: an animated QR to read back
```

## 3. Memory: what the 520KB goes on

```mermaid
flowchart LR
    subgraph ram["RAM, 520KB"]
        pool["WAMR pool, 160KB<br/>parser.wasm's linear memory and UR reassembly"]
        heap["shared heap, 92KB<br/>quirc while reading, then the PSBT buffers"]
        stack["stack, 32KB"]
        other["UI, qrcodegen, core, secp256k1, pico-sdk: 58KB"]
        wasmcopy["parser.wasm's copy in RAM, 16KB"]
        free["free, 162KB"]
    end
```

- **quirc (90KB) and the PSBT buffers (66KB) use the same heap one after the other.** Once reading is
  done quirc is not needed, and before parsing the PSBT buffers are not needed. Measured on the
  hardware, the peak stays at 93,696 B; without sharing it would be 159,232 B
- AOT makes `parser.wasm` faster but has to be expanded into RAM — executing in place measured seven
  times slower — which pushes the pool to 277KB and no longer leaves room for the camera. With the
  parser this light, a full round only changes by 8%, so **the interpreter stays**

## 4. Measured (Pico 2 H, 150MHz)

| step | where it runs | time |
|---|---|---|
| SeedQR to seed (PBKDF2, 2048 rounds) | native | 0.47s |
| capturing one QR frame | PIO + DMA | 120ms |
| decoding the QR | quirc | 62ms, or 300ms when it finds one |
| parsing the PSBT | **parser.wasm** | 25ms |
| checking it and building the display | native | 147ms |
| signing (two inputs, ECDSA + Schnorr) | native | 126ms |
| taking the signatures back | **parser.wasm** | 0.8ms |
| UR encoding and building the QR | wasm + native | 95ms per part |

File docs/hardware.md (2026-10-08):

# Current hardware and wiring

## Parts for the current build

| Part | Model / type | Qty. | Notes |
|---|---|---:|---|
| Microcontroller board | Raspberry Pi Pico 2 H (RP2350) | 1 | Main board |
| Breadboard | EIC-102J | 1 | Pico 2 H, display, switches, and wiring |
| Display | M154-240240-RGB (ST7789V, 1.54 inch) | 1 | Header fitted; no soldering needed |
| Camera | OV7675 board, Arducam B0070 | 1 | 3.3V supply; connected with male-to-female jumper wires |
| Tactile switches | TVDP01-G73BB | 2 | Next and approve; a third switch is spare |
| Debug probe | Raspberry Pi Debug Probe | 1 | SWD flashing and UART logs; includes the SH-SH SWD cable |
| USB cables | Data cables for the Pico and Debug Probe | 2 | One for each board |
| Jumper wires | Male-to-male and male-to-female | As needed | For signal and power connections |

The pin assignment must match `src/board_pins.h`. Always compare the silkscreen on the actual part
against its pin numbers before wiring anything. The OV7670 and OV2640 boards and the joystick below
are alternatives or earlier experiments; they are not part of this build.

## GPIO assignment in the current build

| GPIO | pin | what | goes to |
|---|---|---|---|
| GP0 | 1 | UART0 TX | the Debug Probe's UART "RX" |
| GP1 | 2 | unused | spare |
| GP2-GP9 | 4-7, 9-12 | camera D0-D7 | consecutive, because PIO reads all eight as a run |
| GP10 | 14 | camera PCLK | |
| GP11 | 15 | camera HREF | |
| GP12 | 16 | camera VSYNC | |
| GP13 | 17 | unused | spare |
| GP14 | 19 | camera SIO-D (I2C1 SDA) | |
| GP15 | 20 | camera SIO-C (I2C1 SCL) | |
| GP16 | 21 | panel DC | |
| GP17 | 22 | next button | tactile switch to GND |
| GP18 | 24 | panel SCL (SPI0 SCK) | |
| GP19 | 25 | panel SDA (SPI0 TX) | |
| GP20 | 26 | unused | spare |
| GP21 | 27 | camera XCLK (CLOCK GPOUT0) | OV7670 / OV7675 only; spare on an OV2640 board with a crystal |
| GP22 | 29 | unused | spare |
| GP26 | 31 | approve button | tactile switch to GND |
| GP27 | 32 | unused | spare |
| GP28 | 34 | unused | spare |

Things to watch when building this on a breadboard:

- **The Pico's board covers columns D to G**, so in rows 1 to 20 only columns A and B (left of C) and
  I and J (right of H) are usable. To feed 3V3 and GND to several things, run one lead from the Pico
  and daisy-chain them along the rows on the peripheral side
- The M154-240240-RGB panel **arrived with its header already fitted**, so no soldering was needed.
  Its board overhangs towards the panel, so putting the pin row in an outer column (J, say) and
  letting the panel hang off the edge of the board leaves the next column free to wire
- On the TVDP01-G73BB tactile switches, the two pins that straddle the channel turned out to be the
  connected pair: pressing joins row n to row n+2. Take GND from row n and the signal from row n+2.
  If one does not respond, `button_test.uf2` shows which GPIO actually goes low
- The current build uses two buttons to step through the review screens: "next" (GP17) and "approve" (GP26)

- GP23 (power control), GP24 (VBUS sense), GP25 (LED) and GP29 (VSYS monitor) are used by the board
  itself and not brought out
- That the peripherals in use (UART0, I2C1, SPI0, CLOCK GPOUT0) can reach the pins above was checked
  against the FUNCSEL tables in pico-sdk's `io_bank0.h`
- Signals that are tied off: panel CS to GND, panel RES to 3V3, panel BLK to 3V3, camera RESET to the
  camera's I/O supply, camera PWDN to GND
- 3V3(OUT) (pin 36) feeds the panel and the camera. GND is on pins 3, 8, 13, 18, 23, 28,
  33 and 38

The wiring of the breadboard as actually built is in [docs/breadboard.md](breadboard.md).

## Wiring, part by part

### The M154-240240-RGB panel (ST7789V, 8 pins)

| panel | goes to |
|---|---|
| GND | GND |
| VCC | 3V3 (2.4 to 3.3V; not 5V) |
| SCL | GP18 |
| SDA | GP19 |
| RES | 3V3 (reset at startup is done with the SWRESET command) |
| DC | GP16 |
| CS | GND |
| BLK | 3V3 (on a GPIO this could be dimmed with PWM; for now the QR's white level stands in) |

Because CS is tied off, SPI runs in mode 3 (CPOL=1, CPHA=1) — see `src/drivers/st7789.c`.
If the image is mirrored or offset, the things to fix are `MADCTL` (0x36) and the window setup.

### Optional: the AE-SKRHAAE010-BO joystick (8 pins, needs soldering)

Checked against Akizuki's schematic (`AE-SKRHAAE010-BO.pdf`). Every direction and the press are
already pulled up to +V through 10k and go to GND when pressed.

| kit | goes to |
|---|---|
| +V | 3V3 |
| GND (two of them) | GND |
| SW | GP26 |
| A (UP) | GP13 |
| B (RIGHT) | GP22 |
| C (LEFT) | GP20 |
| D (DOWN) | GP17 |

### Tactile switches (two used)

The current build uses two TVDP01-G73BB switches: next on GP17 and approve on GP26. One side goes to
the GPIO and the other to GND; the RP2350's internal pull-ups are enabled.

### The camera

#### Alternative: the OV7670 board, ST-HL-08-V1 (24-pin DIP)

Pin assignment per Akizuki's reference document: 1 AVDD, 2 AGND, 3 DOGND, 4 DVDD, 5 DOVDD, 6 PWDN,
7 RESET, 8 STROBE, 9 VSYNC, 10 PCLK, 11 SIO-C, 12 SIO-D, 13 XCLK, 14 HREF, 15 VREF1, 16 VREF2,
17-24 D0-D7.

**This board has no power supply on it.** The sensor wants AVDD 2.45 to 3.0V, DVDD 1.62 to 1.98V and
DOVDD 1.7 to 3.0V, so the Pico's 3V3 straight in exceeds AVDD's 3.0V maximum. Building it the way
Akizuki's document says needs extra parts:

| for | part (Akizuki) | price |
|---|---|---|
| DVDD 1.8V | UT7500L-18-T92-B (TO-92; its pins are 1=VOUT / 2=GND / 3=VIN, the reverse of the 78L series) https://akizukidenshi.com/catalog/g/g110491/ | ¥30 |
| its input and output capacitors | 10µF ceramic, two https://akizukidenshi.com/catalog/g/g108155/ | ¥120 |
| AVDD / DOVDD 3.0V | NJM2884U1-03 (SOT-89-5, surface mount) https://akizukidenshi.com/catalog/g/g110896/ | ¥40 |
| a carrier for it | AE-SOT89 (ten) https://akizukidenshi.com/catalog/g/g110835/ | ¥70 |
| its output and input capacitors | 2.2µF https://akizukidenshi.com/catalog/g/g108152/ and 1µF https://akizukidenshi.com/catalog/g/g131472/ | ¥60 |
| VREF1 / VREF2 | 0.1µF (ten) https://akizukidenshi.com/catalog/g/g113582/ | ¥100 |
| SIO-C / SIO-D pull-ups | 4.7k (a hundred) https://akizukidenshi.com/catalog/g/g116472/ | ¥100 |

Akizuki has no TO-92 part for the 3.0V LDO, so that one means soldering a surface-mount package. The
lens is fixed focus, and the datasheet's depth of field is about 20cm.

#### Current camera: the OV7675 board, Arducam B0070 (single 3.3V supply)

https://akizukidenshi.com/catalog/g/g113201/. The signals are the same 8-bit parallel set as the
OV7670 (VSYNC / HREF / PCLK / XCLK / SCL / SDA) and work with the GPIO assignment above. This is the
camera used in the current build; it needs no added power supply.

#### Alternative: an OV2640 board (Nissho Technology, 18 pins, 3.3V)

https://www.csun.co.jp/SHOP/2022031501.html (¥1,045, low stock). It carries a 12MHz crystal, so XCLK
(GP21) is not needed. The M12 mount lens should focus by turning, though the page does not say so
outright. Pins: 1 VCC (3.3V), 2 GND, 3 VS, 4 SCL, 5 HS, 6 SDA, 7 RESET, 8-15 D0-D7, 16 PCLK, 18 PWDN.

### The Debug Probe

- The "D" port (SWD) to the Pico 2 H's debug connector (JST SH, 3 pins). The supplied SH-SH cable fits
  as is
- The "U" port (UART): RX to GP0, GND to GND. TX is unused
- The Pico 2 H itself is powered from the PC over a separate USB cable

## Flashing and the UART

Writing over the Debug Probe's SWD is the quick way. No BOOTSEL, no unplugging USB, and it can reset
the board afterwards.

```
make deps-openocd                            # once (builds Raspberry Pi's fork)
make flash-swd ELF=build/rp2350/app.elf      # flash
make run ELF=build/rp2350/app.elf SECONDS=90 # flash, start listening, reset
make monitor SECONDS=60                      # listen only
```

Upstream OpenOCD (Homebrew's 0.12.0, and HEAD) cannot reach Hazard3 through the DAP and dies on
`target/rp2350.cfg`'s `target create ... riscv -dap`. Raspberry Pi's fork has `target/rp2350-riscv.cfg`.

Flashing a `.uf2` from BOOTSEL (`make flash`) is still there, but macOS's removable-volume permissions
sometimes refuse the `cp`, in which case drag it in Finder.

## Bring-up, in order, as parts arrived

1. With nothing but the Pico 2 H and the Debug Probe, flash `build/rp2350/signer.uf2` and confirm the
   measured signing times appear on the UART at 115200. `psbt_bench.uf2` times a full PSBT round
   (done; `docs/signing-architecture.md` §11)
2. **Before soldering anything**: put three tactile switches in the breadboard (GP17 next, GP26
   approve, GP27 reject, each to GND) and flash `build/rp2350/app_nolcd.uf2`. The review screens' text
   comes out on the UART instead of the panel, so the buttons, the screen flow, approving and signing,
   and the UR output can all be checked with nothing else wired
3. **Done (2026-10-01)**: wired the panel and two tactile switches and flashed `build/rp2350/app.elf`.
   Five review screens appeared; stepping through all of them and approving produced a signature
   (129ms for two inputs) and the signed PSBT came back as an animated QR. The joystick was not
   needed — next (GP17) and approve (GP26) were enough. Reading it with a wallet was still unverified
4. **Done (2026-10-02)**: wired the camera (OV7675 / Arducam B0070). Read PID 0x76 and VER 0x73, and
   captured QVGA successfully: 191ms per frame, about 5.2fps, with quirc decoding in 61ms.
   `camera_test.uf2` shows the captured QVGA scaled down on the LCD, reads QRs with our quirc fork, and
   puts the capture and decode times and whatever was read on the UART. It also prints the PID read
   over SCCB (0x76 for an OV7670), which makes it useful for checking the wiring

## Camera capture (`src/drivers/camera.*`)

- PIO (`camera.pio`) picks out only the Y of YUV422 (Y U Y V) and DMA writes QVGA greyscale (76.8KB)
  straight into the buffer. It captures directly into quirc's image buffer, so there is no second
  framebuffer
- Every capture restarts from waiting on VSYNC, so starting partway through a frame still gets the next
  one from its first row. The end of a row is found by waiting for HREF to fall
- **This can be verified on the hardware with no camera attached**
  (`make run ELF=build/rp2350/pio_loopback_test.elf`): another state machine in the same PIO generates
  the DVP waveform (D0-D7, PCLK, HREF, VSYNC) and the capture side reads those same pins, which needs
  no wiring because PIO inputs read the pads. On 2026-09-25 this ran on the hardware at PCLK 1.5, 6.25
  and 25MHz, including starting mid-frame, and every captured pixel matched the Y that was generated.
  25MHz is the same rate as the XCLK given to an OV7670; a 64x8 frame's theoretical 61µs measured 65µs
- XCLK is the clock output on GP21 (150MHz / 6 = 25MHz). SCCB is I2C1 at 100kHz
- `camera_ov7670.c` provides the current QVGA YUV configuration, which has been verified with the
  OV7675 board. The OV2640 needs a separate configuration and has not been tested
- Verification without hardware: `make check-camera-sim` runs pioasm's output through a minimal PIO
  simulator. Against a synthesised DVP waveform (VSYNC, HREF, blanking, HREF arriving late, starting
  mid-frame) the captured pixels match the Y. A version with the end-of-row HREF wait removed fails on
  the waveform where HREF lags PCLK. Electrical timing (data setup and hold) can only be checked on the
  hardware

`app.uf2` signs with the seed from BIP39's test vector (`abandon ... about`). It must never hold funds.

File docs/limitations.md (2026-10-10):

# Limitations

What this signer accepts, what it refuses, and what it deliberately does not do.
Written so a reviewer can tell a bug from a documented boundary. If something here surprises you,
that is worth [reporting](../SECURITY.md) even though it is listed.

## Status

Not reviewed by a third party. signet only. See [Disclaimer](../README.md#disclaimer).

## Transactions

- **PSBT v0 only** (BIP174). v2 is rejected.
- The firmware signs P2WPKH (BIP84), P2TR key-path (BIP86) and **P2WSH multisig of at most three keys**
  (BIP48, `m/48'/coin'/account'/2'`). The device holds no cosigner keys, so P2WSH change is shown as an
  external address to check by eye, and the Core wallet combines the cosigners' PSBTs.
  A P2WSH spend of two or more inputs needs `non_witness_utxo`, as P2WPKH does.
- **[BIP39](https://github.com/bitcoin/bips/blob/master/bip-0039.mediawiki) passphrase input is planned but not available in the firmware yet.** The shared `signer.wasm`
  interface accepts a passphrase; the Pico firmware currently derives the seed with an empty passphrase.
- At most **16 inputs and 16 outputs**, and a PSBT of at most **32,768 bytes**.
- scriptPubKey at most **83 bytes** (the standard OP_RETURN limit; P2TR and P2WSH are 34).
- Script-path taproot spends, miniscript, and time locks beyond nLockTime passthrough are not handled.
- Every input must carry `witness_utxo` or `non_witness_utxo`. When both are present, the previous
  transaction must hash to the stated txid and its output must match the `witness_utxo`.
- Signatures are **deterministic**: the same PSBT always produces the same bytes. BIP340 `aux_rand`
  is zero, as in Bitcoin Core, Trezor, Jade and BDK. P2WSH multisig is unaffected: each cosigner makes its
  own ECDSA signature. Before MuSig2 or FROST, the nonce strategy must change: [BIP340](https://github.com/bitcoin/bips/blob/master/bip-0340.mediawiki) says multisignature schemes are insecure with deterministic nonce generation.

## What the device checks before it signs

- It derives every key itself and compares the resulting scriptPubKey with the one in the PSBT.
  A claimed derivation path is never trusted on its own.
- An output counts as change only if the device re-derives it and the script matches.
- The fee is computed from input and output amounts the device has verified, and shown.
- Signing requires the same plan that was reviewed: `core_sign` recomputes the SHA-256 of the
  reviewed plan and refuses if it differs. What you approved is what gets signed.

## What it does not check

- **It cannot tell you whether an address belongs to the person you think.** Verify the destination
  out of band.
- It does not know the current fee market. A reasonable-looking fee can still be wrong.
- It does not see the chain. It cannot know whether an input is already spent, or whether a
  `non_witness_utxo` is a real confirmed transaction.
- It does not implement anti-exfil (sign-to-contract). A malicious firmware could bias nonces;
  reproducible builds and the on-screen parser hash are the defence offered instead.

## Keys and memory

- The seed exists **only in RAM**, never in flash. Scanning it again after a power cycle is required.
- While unlocked, the master key and chain code are in RAM — they must be, to sign.
  **An attached debug probe (SWD) can read them.** Measured: see
  [docs/signing-architecture.md](signing-architecture.md). Disconnect the probe for real use.
- `Lock (wipe seed)` zeroes them; this was verified by dumping RAM before and after.
- The mnemonic, the BIP39 seed, the SeedQR payload, the camera frame and derived child keys are
  wiped after use, and signing nonces do not survive — all verified with `tools/security/ram_keys.py`.
- Entering the USB bootloader (BOOTSEL) clears SRAM entirely, so that path cannot read a leftover key.
- Nothing defends against an attacker who can glitch or probe the chip at will. Signatures are
  verified before they leave the device and the secp256k1 context is re-randomized per signing
  session, which raises the cost; it does not make the device tamper-resistant.

## QR and transport

- Animated QR uses UR (BCR-2020-005) fountain encoding; fragments are 100 bytes so each frame stays
  at QR version 8, which is what a phone camera can read from a 240x240 display.
- A PSBT whose previous transactions are large may not fit. Strip `non_witness_utxo` for segwit
  inputs (`tools/psbt/strip_psbt.py`); a faucet transaction with 2,323 outputs made a PSBT of 77KB,
  which is 770 QR frames.
- The device's quirc decoder needs the code to fill most of the frame and cannot read a display from
  across a room.
- A QR decoder is not a trust boundary. Whatever it produces is parsed and re-validated.

## Hardware

- One board is supported: Raspberry Pi Pico 2 (RP2350, RISC-V Hazard3). No other target is tested.
- There is no secure element, no tamper detection, no encrypted storage, and no battery-backed RAM.
- The boot ROM of the RP2350 is not open source.
- Builds with `TEST_SEED=1` can select a published test seed. Never put funds on such a build.

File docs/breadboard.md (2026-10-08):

# Breadboard Wiring

<sup>[日本語](ja/breadboard.md)</sup>

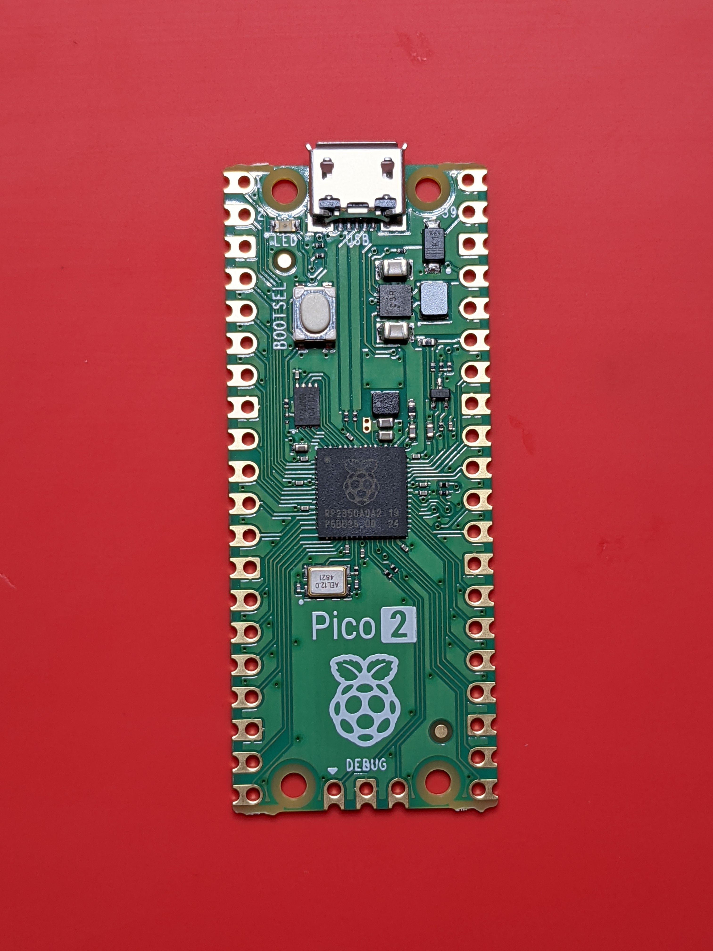
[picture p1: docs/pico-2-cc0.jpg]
Raspberry Pi Pico 2


Photo: [Profpcde / Wikimedia Commons](https://commons.wikimedia.org/wiki/File:Top_view_of_a_Raspberry_Pi_Pico_2_microcontroller_board.jpg), CC0 1.0. Raspberry Pi is a trademark of Raspberry Pi Ltd. This project is not endorsed by Raspberry Pi Ltd. The build uses a Pico 2 H.

This documents the wiring as built. Update this page when the wiring changes. The logical pin assignments are in [hardware.md](hardware.md); the firmware definitions are in [src/board_pins.h](../src/board_pins.h).

The wiring is also defined in machine-readable files.

| File | Contents | Generate with |
|---|---|---|
| [breadboard.yml](breadboard.yml) | Hole-to-hole connections | `make breadboard` generates the breadboard layout (SVG) |
| [wiring.yml](wiring.yml) | Signal connections (WireViz) | `make wiring` generates the wiring diagram, bill of materials, and HTML |

Update this page and both YAML files when the wiring changes.

## Diagrams

### Signal connections

Wiring diagram

### Physical layout

Breadboard hole layout

## Setup

- Breadboard: EIC-102J. Insert the Pico 2 H across columns **C and H**, rows **1–20** (row 1 is at the USB end).
- The Pico board covers columns D–G, so in rows 1–20 only columns **A and B** (left of C) and **I and J** (right of H) are accessible.
- Use one wire per hole. Use another hole in the same row if needed; holes in a row are electrically connected.

## Row and pin mapping

| Row | Column C (physical pin = row number) | Column H (physical pin = 41 - row number) |
|---|---|---|
| 1 | GP0 (UART TX → Debug Probe) | VBUS |
| 2 | GP1 | VSYS |
| 3 | GND | GND |
| 4 | GP2 (camera D0) | 3V3_EN |
| 5 | GP3 (camera D1) | **3V3 OUT** |
| 6 | GP4 (camera D2) | ADC_VREF |
| 7 | GP5 (camera D3) | GP28 |
| 8 | GND | AGND |
| 9 | GP6 (camera D4) | GP27 |
| 10 | GP7 (camera D5) | GP26 (confirm) |
| 11 | GP8 (camera D6) | RUN |
| 12 | GP9 (camera D7) | GP22 |
| 13 | GND | GND |
| 14 | GP10 (camera PCLK) | GP21 (camera XCLK) |
| 15 | GP11 (camera HREF) | GP20 |
| 16 | GP12 (camera VSYNC) | GP19 (LCD SDA) |
| 17 | GP13 | GP18 (LCD SCL) |
| 18 | GND | GND |
| 19 | GP14 (camera SDA) | GP17 (next button) |
| 20 | GP15 (camera SCL) | GP16 (LCD DC) |

## Debug Probe (including connections off the breadboard)

| From | To | Notes |
|---|---|---|
| D port (SWD) | Pico 2 H debug connector (3-pin connector at board edge) | Included SH-SH cable; used for flashing |
| U port RX | **A1** (GP0 = UART TX) | Receives logs; do not use TX |
| U port GND | **A3** or **B3** (GND) | |
| Debug Probe USB | PC | |
| Pico USB | PC (power) | Separate cable |

## Power rails

| From | To | Notes |
|---|---|---|
| F42 (free hole on the same row as the LCD 3V3 connection) | Red rail outside column **A**, around row 42 | 3V3 |
| B13 | Blue rail outside column **A**, around row 13 | GND (directly connected to Pico) |

Rail holes are grouped in sets of five and do not map one-to-one to breadboard row numbers. Holes in the same half of a rail are electrically connected. Many boards split the rails at the center, so 3V3 uses the rear half (feed at 42, takeoffs at 45 and 47) and GND uses the front half (feed at 13, takeoffs at 9 and 10).

There are two sets of rails, outside columns A and J. **Use the A-side rails.** The LCD covers rows 36–43 on the J side, making those holes hard to reach. The camera's SCL and SDA connections (B19 and B20) are also on the A–E side. On boards with rails split at the center, the two halves are separate.

Pico 3V3 OUT (physical pin 36 = H5) is already occupied at row 5, so tee off the 3V3 line going to the LCD.

## LCD M154-240240-RGB (rows 36–43, column J; the display overhangs the board)

| Row | LCD pin | Wiring |
|---|---|---|
| 36 | BLK | 3V3 (jumper from row 39) |
| 37 | CS | GND (jumper from row 43) |
| 38 | DC | I38 → I20 (GP16) |
| 39 | RES | 3V3 (jumper from row 42) |
| 40 | SDA | I40 → I16 (GP19) |
| 41 | SCL | I41 → I17 (GP18) |
| 42 | VCC | I42 → I5 (3V3 OUT) |
| 43 | GND | I43 → J18 (GND) |

Chain 3V3 from row 42 to 39 to 36, and GND from row 43 to 37. Use any free hole in the same row.

## Buttons (tactile switches across the center gap)

The switch legs go into rows n and n+2. Pressing a switch connects those two rows.

| Switch | Rows | GND side | Signal side | Action |
|---|---|---|---|---|
| SW1 | 24 / 26 | A24 → I18 (GND) | J26 → I19 (GP17) | Next |
| SW2 | 28 / 30 | B24 → A28 (GND jumper) | J30 → I10 (GP26) | Confirm |

If a joystick is added, it also uses UP=GP13 (C17), LEFT=GP20 (H15), and RIGHT=GP22 (H12).

## OV7675 camera (Arducam B0070, 2×10, 20 pins)

Pin order follows the silkscreen on the board: odd-numbered pins are on the left, even-numbered pins on the right.

| Pin | Name | Connect to | Stage |
|---|---|---|---|
| 1 | VCC | Red rail 45 | 1 |
| 2 | GND | Blue rail 9 | 1 |
| 3 | SCL | B20 (GP15) | 1 |
| 4 | SDA | B19 (GP14) | 1 |
| 5 | VS | B16 (GP12) | 2 |
| 6 | HS | B15 (GP11) | 2 |
| 7 | PCLK | B14 (GP10) | 2 |
| 8 | XCLK | I14 (GP21) | 1 |
| 9 | D7 | B12 (GP9) | 2 |
| 10 | D6 | B11 (GP8) | 2 |
| 11 | D5 | B10 (GP7) | 2 |
| 12 | D4 | B9 (GP6) | 2 |
| 13 | D3 | B7 (GP5) | 2 |
| 14 | D2 | B6 (GP4) | 2 |
| 15 | D1 | B5 (GP3) | 2 |
| 16 | D0 | B4 (GP2) | 2 |
| 17 | NC | - | - |
| 18 | NC | - | - |
| 19 | PEN | Red rail 47 (enables the board's power) | 1 |
| 20 | PDN | Blue rail 10 (releases power-down) | 1 |

The 2-row header cannot plug directly into the breadboard because it cannot straddle the center gap. Use male-to-female jumper wires.

For **stage 1** (7 wires), run `make run ELF=build/rp2350/camera_test.elf`. A `PID 0x76` result confirms power, I2C, and XCLK. Add the 11 stage 2 wires only after this passes.

At startup, `camera_test` reports GP2–GP17 states and edge counts for PCLK, HREF, and VSYNC. **The edge counts help identify which signals are connected** (in 100 ms: about 100,000 PCLK edges, 1,300 HREF edges, and 2 VSYNC edges). This helps find wiring mistakes. The left column (VCC, SCL, VS, PCLK, D7, …) and right column (GND, SDA, HS, XCLK, D6, …) are easy to swap.

## Wire count

| Group | Count | Status |
|---|---:|---|
| Debug Probe (2 UART wires + SWD cable + 2 USB cables) | 2 + 3 | Done |
| Power rails (3V3, GND) | 2 | Done |
| LCD | 8 | Done |
| Two buttons | 4 | Done |
| Camera stage 1 | 7 | Done (PID 0x76 / VER 0x73 confirmed) |
| Camera stage 2 | 11 | Done (capture succeeds) |
| **Total (complete build)** | **34** | |

Adding a joystick takes 8 connections (+V, two GND, SW, A, B, C, D) and replaces the four wires for the two tactile switches.

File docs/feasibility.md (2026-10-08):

# Feasibility and performance measurements

This page combines the RP2350 memory and performance studies for the current device, QR decoding,
and earlier experiments with running the complete signer in WebAssembly. The signer WASM results are
historical: the current firmware runs the signing core natively and uses WASM for transaction parsing.

## Current device

The current application uses about 341KB of the RP2350's 520KB SRAM. QR decoding and PSBT processing
share the heap: quirc is released after scanning, before the PSBT buffers are allocated.

| Item | Size | Basis |
|---|---:|---|
| WAMR pool, including parser.wasm memory and UR assembly | 160KB | 152,792 bytes maximum measured use |
| parser.wasm copy in RAM | 16KB | Rewritten by the interpreter while loading |
| Shared heap | 92KB | 93,696 bytes peak measured with `mallinfo` |
| Stack | 32KB reserved | 23KB measured; the default 2KB is insufficient |
| UI, qrcodegen, core, secp256k1, pico-sdk and other use | 42KB | Remainder of the application |
| **Total** | **about 341KB / 520KB** | |

The shared heap holds about 90KB for quirc while scanning, then about 66KB for PSBT buffers. Without
sharing, the peak would be 159,232 bytes. About 180KB remains; double-buffering the camera would use
another 77KB.

## QR decoding on the RP2350

These measurements cover quirc and qrcodegen on QEMU RV32 (`-icount shift=0`) and Pico 2 H hardware
at 150MHz. Synthetic camera-like images were stored in Flash and run with
`make run ELF=build/rp2350/qr_bench.elf`.

### Synthetic image generation

`tools/generate/gen_qr_frames.py` puts one UR QR code (`UR:CRYPTO-PSBT/12-30/...`, uppercase alphanumeric mode,
ECC L) into a 320×240 grayscale image. It applies a 5° rotation, Gaussian blur, noise σ=4, 25% side
and 15% top/bottom illumination variation, and contrast from 40 to 210.

| UR fragment | QR version | Modules |
|---|---:|---:|
| 50 bytes | v5 | 37 |
| 100 bytes | v8 | 49 |
| 200 bytes | v11 | 61 |

### Read success by QR size and blur

| QR | Span (px) | px/module | Blur σ | quirc | zxing-cpp |
|---|---|---|---|---|---|
| v5 | 220 / 190 / 160 | 5.9 / 5.1 / 4.3 | 0.5, 1.0 | all pass | all pass |
| v8 | 220 | 4.5 | 0.5 / 1.0 | pass / fail | pass / pass |
| v8 | 190 | 3.9 | 0.5 / 1.0 | pass / pass | pass / pass |
| v8 | 160 | 3.3 | 0.5 / 1.0 | pass / fail | pass / pass |
| v11 | 220 | 3.6 | 0.5 / 1.0 | pass / fail | pass / pass |
| v11 | 190 | 3.1 | 0.5 / 1.0 | fail / fail | pass / pass |
| v11 | 160 | 2.6 | 0.5 / 1.0 | fail / fail | pass / fail |

The v8 failures are not monotonic: one occurs at the largest 220px span. These results use generated
images and do not predict camera performance on their own.

### Instructions per frame (RV32)

| Operation | v5 | v8 | v11 |
|---|---:|---:|---:|
| Decode (upstream quirc, double) | 370M | 622M | - |
| Decode (upstream quirc, float) | 231M | 388M | - |
| Decode (patched quirc, float) | 22.5–23.2M | 35.8–36.6M | 40.7M |
| Frame with no QR found | 2.9–3.9M | | |
| Generate QR (qrcodegen) | 4.5M | 7.8M | 12.2M |
| Draw 240×240 RGB565 one row at a time | 1.5M | 1.6M | 1.5M |

Upstream quirc calls `fitness_all` 81 times from `jiggle_perspective`. A frame calls `perspective_map`
about 430,000 times at roughly 1,300 instructions each, accounting for nearly all decode time. The
fixed-point patch converts coefficients once per `fitness_all`; `fitness_cell` then uses 32×32→64-bit
multiplication and 32-bit division, falling back to floating point if coefficients are out of range.

The fixed-point `mcu` branch of [habakan/quirc](https://github.com/habakan/quirc) brought synthetic
v5 and v8 decoding to 23M and 36M instructions. After divide-by-zero and overflow fixes, they took
26.8M and 43M. Its 800-image comparison reported no incorrect reads; 789 results matched upstream.
Building with `-mcpu=hazard3-rp2350 -O2` emits the Hazard3-specific Xh3bextm instruction, which QEMU
does not support. The QEMU build used
`-march=rv32imac_zicsr_zifencei_zba_zbb_zbs_zbkb_zcb_zcmp`.

### Pico 2 H measurements (150MHz, 2026-09-25)

Eighteen generated frames were stored in Flash and run on the device.

| Operation | v5 | v8 | v11 | Effective CPI |
|---|---:|---:|---:|---:|
| Decode (patched quirc) | 0.278–0.285s | 0.447–0.453s | 0.494s | 1.57 |
| Frame with no QR found | 0.029–0.038s | | | 1.48 |
| Generate QR (qrcodegen) | 0.034s | 0.058s | 0.091s | 1.12 |
| Draw 240×240 RGB565 one row at a time | 0.021s | 0.022s | 0.020s | 2.07 |

Read successes and failures matched QEMU, including two v8 failures and three v11 failures. quirc's
effective CPI was 1.57, compared with 7.5 for AOT signing code. The frame buffer is in RAM and the hot
functions are small. Drawing's CPI of 2.07 is dominated by writes to the row buffer. Measured
throughput was 3.6 fps for v5 and 2.2 fps for v8; frames with no readable QR returned in 30ms.

### OV7675 camera measurements (2026-10-02)

An OV7675 (Arducam B0070) was connected to the Pico 2 H. `camera_test` read actual QR images and
reassembled a v5 QR (about a 50-byte UR fragment).

| Operation | Measurement |
|---|---:|
| Capture | 120ms (VGA frame plus VSYNC wait, about 8fps) |
| Decode, no QR | 62ms |
| Decode, QR found | 300ms (grid extraction and error correction) |
| Effective rate | about 2.5fps |

The OV7675's vertical downscaling (`SCALING_DCWCTR`) did not work. The sensor outputs VGA YUV422;
PIO keeps the first Y from each `Y U Y V` pair and skips every other row to produce 320×240. This
does not depend on sensor scaling (`src/drivers/camera.pio`). The same frame may decode or return
`ECC failure`; camera shake and exposure matter, and adequate lighting improves the success rate.
At startup, `camera_test` reports GP2–GP17 states and PCLK, HREF, and VSYNC edge counts to help find
wiring mistakes.

The current design keeps QR decoding native and in the TCB. Putting it in WASM would make it about
80 times slower, over ten seconds per frame even with the fixed-point patch. Synthetic QVGA frames
decode through v8, but real camera reliability at v8 has not been established. The current quirc fork
also carries unmerged security fixes (#158, #159), UBSan and fuzzing work, and a fix for
NaN-to-integer conversion in upstream `perspective_map()`; see its `mcu/README.md`.

QR generation is not the bottleneck: drawing a v11 QR on the 240×240 LCD took under 14 million
instructions. For animated output, 100-byte fragments keep frames at v8. Larger PSBTs, especially
those carrying full previous transactions, can require many frames.

### QR reproduction

```sh
make deps
make check-qemu-qr
make check-qemu-qr QUIRC=third_party/quirc/lib QUIRC_DEFS=  # upstream quirc (double)
make check-qr-mac
make run ELF=build/rp2350/qr_bench.elf                    # hardware, via SWD and UART
```

## Earlier experiments: signer and key derivation in WASM

The following measurements use the former `bitcoin-signer.wasm`, removed from jitsu-in v0.1.0. They
are retained as historical evidence for the performance and memory trade-offs. They do not describe
the current firmware, whose signing core is native.

### QEMU instruction counts (RV32)

| Operation | RV32 native | WAMR classic | WAMR fast | Classic + host SHA-512 |
|---|---:|---:|---:|---:|
| PBKDF2 (BIP39 seed) | 66.4M | 1,693M | 1,030M | 300M |
| BIP32 `m/84'/0'/0'/0` | 2.2M | 161M | 95M | 154M |
| BIP32 `m/84'/0'/0'/0/0` | 3.2M | 239M | 142M | 231M |
| ECDSA signing | 1.0M | 82M | 49M | 82M |

For the standalone signer study, classic interpreter configurations measured 82.2M instructions for
ECDSA and 153.5M for Schnorr with a 2KB `ecmult_gen` table. A 22KB table reduced those counts to
63.5M and 116.0M at a 20KB RAM cost. Fast interpreter measured 48.5M and 90.7M.

PBKDF2's 64-bit SHA-512 arithmetic made the interpreter especially slow. Importing only the
SHA-512 compression function reduced PBKDF2 from 1,693M to 300M instructions; BIP32 improved little
because public-key calculation dominated its cost. At an estimated CPI of 1–1.5, classic plus host
SHA-512 put seed generation at 2–3 seconds and signing one input at 2.1–3.1 seconds. Caching the
account key would reduce repeated derivation work.

### Pico 2 H measurements (150MHz, 2026-09-25)

| Operation | Classic interpreter | Classic + host SHA-512 | AOT XIP | AOT expanded into RAM |
|---|---:|---:|---:|---:|
| ECDSA signature | 0.696s | 0.696s | 0.319s | **0.041s** |
| Schnorr signature | 1.297s | 1.298s | 0.622s | **0.078s** |
| BIP39 seed (PBKDF2, 2048 rounds) | 14.81s | 3.053s | 0.979s | **0.832s** |
| BIP32 `m/84'/0'/0'/0/0` | 2.029s | 1.960s | 0.937s | **0.122s** |
| Runtime initialization | 16.9ms | 16.9ms | 2.5ms | 1.4ms |
| Flash | 125.4KB | 124.2KB | 228.6KB | 228.1KB |
| RAM | 135.3KB | 133.0KB | **68.9KB** | 347.5KB |
| Maximum WAMR pool | 36.7KB | 36.0KB | 34.9KB | 277.3KB |

All four configurations produced signatures, seeds, and public keys matching QEMU and Mac native
results. The interpreter's measured CPI was 1.27 (1.35 for PBKDF2). AOT expanded into RAM measured
CPI 1.08 and followed QEMU instruction counts. AOT XIP measured CPI 7.5 for secp256k1 paths because
the 150KB generated code exceeded the 16KB XIP cache; PBKDF2 stayed near CPI 1.1 because its SHA-512
compression loop fit in cache. Thus QEMU instruction counts alone did not predict XIP performance.

The AOT QEMU instruction counts were:

| Operation | Native | Classic interpreter | AOT, not XIP | AOT XIP (default) | AOT XIP, more runtime calls |
|---|---:|---:|---:|---:|---:|
| ECDSA signature | 1.05M | 82.2M | 5.68M | 6.42M | 12.2M |
| Schnorr signature | 1.89M | 153M | 10.9M | 12.2M | 23.3M |
| PBKDF2 (BIP39) | 66.4M | 1,693M | 119M | 136M | 177M |
| BIP32 `m/84'/0'/0'/0/0` | 3.19M | 239M | 16.9M | 19.0M | 35.9M |
| Maximum WAMR pool | - | 36.7KB | 272KB | 35.1KB | 35.1KB |

Setting `--bounds-checks=0` reduced ECDSA to 4.33M, PBKDF2 to 97.0M, and BIP32 to 12.9M instructions,
but is not suitable for an MCU security boundary. The default `WAMRC_FLAGS` used `--xip` and limited
runtime calls to operations such as i64 division and remainder; wamrc's broader RISC-V defaults made
the workloads about twice as slow.

RAM-expanded AOT reduced the complete 1-input, 2-output P2WPKH round to about 0.2 seconds, while AOT
XIP took about 1.5 seconds. RAM-expanded code used 347.5KB overall, including a 277.3KB WAMR pool.
That left too little headroom for QR capture buffers in the former whole-signer design. This memory
trade-off, the TCB cost of the AOT loader and build-time LLVM, and the current parser-only WASM
boundary informed the current architecture.

### Runtime and memory constraints found

- The classic interpreter rewrites bytecode while loading, so the WASM image needs a RAM copy.
- WASM data segments, including libsecp256k1 constant tables, occupy linear memory. The study used
  `ECMULT_GEN_KB=2` (`COMB_BLOCKS=2`, `COMB_TEETH=5`) instead of the 86KB default.
- WAMR's shrunk-memory mode can avoid allocating whole 64KB pages when `memory.grow` is unused and
  `__heap_base` / `__data_end` are exported.
- On RV32, libsecp256k1's 10x26 field arithmetic uses many 64-bit operations, which WAMR handles in
  software.
- WAMR classic interpreter's `i64.store` implementation assumed 4-byte alignment; Hazard3 faults on
  some unaligned stores while QEMU does not. The fix from
  [WAMR PR #5123](https://github.com/wasm-micro-runtime/wasm-micro-runtime/pull/5123) is included in
  the pinned revision.
- The RP2350's default 2KB stack was too small; the firmware used a 16KB stack.
- WAMR links libm functions such as `ceil` and `sqrt` even when the signer itself does not use floating
  point, adding them to the trusted computing base.
- RISC-V AOT code written to RAM needs `fence.i`; the firmware added this through `os_icache_flush`.
  The measured QEMU AOT target used `generic-rv32` with `m,a,c,zba,zbb,zbs`, not Hazard3's
  `zbkb`, `zcb`, or `zcmp` extensions.

### Historical signer reproduction

These commands target the removed `bitcoin-signer.wasm`. Check out commit `f2f61c6` before running
them; they do not run against the current tree.

```sh
make check-host
make check-qemu-native
make check-qemu POOL_KB=64
make check-qemu FAST=1 POOL_KB=256
uv run tools/ref_kdf.py
make build/wamrc/wamrc
```

For the former AOT hardware build, the study used `AOT=1`, `RP2350_POOL_KB=320`, and
`--target=riscv32 --target-abi=ilp32 --cpu=generic-rv32 --cpu-features=+m,+a,+c,+zba,+zbb,+zbs
--bounds-checks=1`. Rebuilds required deleting generated `bitcoin-signer.wasm`, AOT, and header files
when switching configurations.

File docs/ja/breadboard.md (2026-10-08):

# ブレッドボードの実配線

<sup>[English](../breadboard.md)</sup>

Raspberry Pi Pico 2

写真: [Profpcde / Wikimedia Commons](https://commons.wikimedia.org/wiki/File:Top_view_of_a_Raspberry_Pi_Pico_2_microcontroller_board.jpg)、CC0 1.0。Raspberry Pi is a trademark of Raspberry Pi Ltd. このプロジェクトは同社の承認を受けたものではありません。実装では Pico 2 H を使用。

実際に組んでいる配線。変えたらこのファイルも直す。論理的なピン割り当ては [hardware.md](../hardware.md)、
定義は [src/board_pins.h](../../src/board_pins.h)。

機械可読な形でも持たせてある。

| ファイル | 内容 | 作り方 |
|---|---|---|
| [breadboard.yml](../breadboard.yml) | 穴の位置まで（どの穴からどの穴へ） | `make breadboard` でブレッドボードの絵（SVG） |
| [wiring.yml](../wiring.yml) | 信号の対応（WireViz） | `make wiring` で配線図・部品表・HTML |

配線を変えたら、このファイルと上の 2 つの YAML を直す。

## 配線図

### 信号のつながり

配線図

### ブレッドボード上の位置

ブレッドボードの穴位置

## 前提

- ブレッドボード EIC-102J。Pico 2 H は **C 列と H 列の行 1〜20** に挿す（USB 側が行 1）
- **Pico の基板が D〜G 列を覆う**ので、行 1〜20 で使える穴は **A・B 列**（C 列の左）と **I・J 列**（H 列の右）だけ
- 1 つの穴に挿せる線は 1 本。同じ行なら別の穴を使う（行内は電気的に同一）

## 行 ↔ ピンの対応

| 行 | C 列（物理ピン = 行番号） | H 列（物理ピン = 41 - 行番号） |
|---|---|---|
| 1 | GP0（UART TX → Debug Probe） | VBUS |
| 2 | GP1 | VSYS |
| 3 | GND | GND |
| 4 | GP2（カメラ D0） | 3V3_EN |
| 5 | GP3（カメラ D1） | **3V3 OUT** |
| 6 | GP4（カメラ D2） | ADC_VREF |
| 7 | GP5（カメラ D3） | GP28 |
| 8 | GND | AGND |
| 9 | GP6（カメラ D4） | GP27 |
| 10 | GP7（カメラ D5） | GP26（承認） |
| 11 | GP8（カメラ D6） | RUN |
| 12 | GP9（カメラ D7） | GP22 |
| 13 | GND | GND |
| 14 | GP10（カメラ PCLK） | GP21（カメラ XCLK） |
| 15 | GP11（カメラ HREF） | GP20 |
| 16 | GP12（カメラ VSYNC） | GP19（液晶 SDA） |
| 17 | GP13 | GP18（液晶 SCL） |
| 18 | GND | GND |
| 19 | GP14（カメラ SDA） | GP17（進む） |
| 20 | GP15（カメラ SCL） | GP16（液晶 DC） |

## Debug Probe（ブレッドボード外を含む）

| から | へ | 内容 |
|---|---|---|
| 「D」ポート（SWD） | Pico 2 H のデバッグ端子（基板端の 3 ピン） | 付属の SH-SH ケーブル。書き込みに使う |
| 「U」ポート RX | **A1**（GP0 = UART TX） | ログの受信。TX は使わない |
| 「U」ポート GND | **A3** または **B3**（GND） | |
| Debug Probe の USB | PC | |
| Pico の USB | PC（給電） | 別ケーブル |

## 電源レール

| から | へ | 内容 |
|---|---|---|
| F42（液晶の 3V3 と同じ行の空き穴） | **A 列の外側**の赤レール、行 42 あたり | 3V3 |
| B13 | **A 列の外側**の青レール、行 13 あたり | GND（Pico 直結） |

レールの穴は 5 個ずつの塊で並び、行番号とは 1 対 1 に対応しない。同じレールの同じ半分なら電気的に同一。
中央で分断されているボードが多いので、3V3 は後ろ半分（引き込み 42、取り出し 45 と 47）、
GND は前半分（引き込み 13、取り出し 9 と 10）に固めてある。

レールは A 列の外側と J 列の外側に 2 組ある。**A 列側を使う**。J 列側の行 36〜43 は液晶の本体が覆っていて挿しにくく、
カメラの SCL / SDA（B19・B20）も A〜E 側にあるため。レールの線が中央で途切れているボードでは、左右が別の列になる。

Pico の 3V3 OUT（物理 36 番 = H5）は行 5 で埋まっているので、液晶へ引いた 3V3 から分岐する。

## 液晶 M154-240240-RGB（行 36〜43、J 列。本体はボードの外へはみ出す）

| 行 | 液晶のピン | 配線 |
|---|---|---|
| 36 | BLK | 3V3（行 39 から渡す） |
| 37 | CS | GND（行 43 から渡す） |
| 38 | DC | I38 → I20（GP16） |
| 39 | RES | 3V3（行 42 から渡す） |
| 40 | SDA | I40 → I16（GP19） |
| 41 | SCL | I41 → I17（GP18） |
| 42 | VCC | I42 → I5（3V3 OUT） |
| 43 | GND | I43 → J18（GND） |

3V3 は 42 → 39 → 36、GND は 43 → 37 と数珠つなぎ。使う穴は空いているものでよい（同じ行なら同一）。

## ボタン（タクトスイッチ、溝をまたぐ）

脚は行 n と行 n+2 に入り、押すとその 2 行がつながる。

| スイッチ | 行 | GND 側 | 信号側 | 役割 |
|---|---|---|---|---|
| SW1 | 24 / 26 | A24 → I18（GND） | J26 → I19（GP17） | 進む |
| SW2 | 28 / 30 | B24 → A28（GND を渡す） | J30 → I10（GP26） | 承認 |

ジョイスティックを付けたら、UP=GP13（C17）、LEFT=GP20（H15）、RIGHT=GP22（H12）も使う。

## カメラ OV7675（Arducam B0070、2×10 の 20 ピン）

基板のシルクどおりの並び。奇数が左列、偶数が右列。

| ピン | 名前 | つなぐ先 | 段階 |
|---|---|---|---|
| 1 | VCC | 赤レール 45 | 1 |
| 2 | GND | 青レール 9 | 1 |
| 3 | SCL | B20（GP15） | 1 |
| 4 | SDA | B19（GP14） | 1 |
| 5 | VS | B16（GP12） | 2 |
| 6 | HS | B15（GP11） | 2 |
| 7 | PCLK | B14（GP10） | 2 |
| 8 | XCLK | I14（GP21） | 1 |
| 9 | D7 | B12（GP9） | 2 |
| 10 | D6 | B11（GP8） | 2 |
| 11 | D5 | B10（GP7） | 2 |
| 12 | D4 | B9（GP6） | 2 |
| 13 | D3 | B7（GP5） | 2 |
| 14 | D2 | B6（GP4） | 2 |
| 15 | D1 | B5（GP3） | 2 |
| 16 | D0 | B4（GP2） | 2 |
| 17 | NC | - | - |
| 18 | NC | - | - |
| 19 | PEN | 赤レール 47（基板の電源を有効にする） | 1 |
| 20 | PDN | 青レール 10（パワーダウン解除） | 1 |

2 列のヘッダはブレッドボードに直接挿せない（溝をまたげない）ので、オス-メスのジャンパ線で引く。

**段階 1**（7 本）で `make run ELF=build/rp2350/camera_test.elf` を実行し、`PID 0x76` が出れば
電源・I2C・XCLK が正しい。そこまで通ってから段階 2 の 11 本を足す。

`camera_test` は起動時に GP2〜GP17 の状態と、PCLK / HREF / VSYNC のエッジ数を出す。
**エッジの数でどの線が来ているかが分かる**（100ms で PCLK は 10 万回、HREF は約 1300 回、VSYNC は約 2 回）。
挿し間違いはこれで特定できる。左列（VCC・SCL・VS・PCLK・D7…）と右列（GND・SDA・HS・XCLK・D6…）の
取り違えが起きやすい。

## 本数

| 区分 | 本数 | 状態 |
|---|---|---|
| Debug Probe（UART 2 本 + SWD ケーブル + USB 2 本） | 2 + 3 | 済 |
| 電源レール（3V3、GND） | 2 | 済 |
| 液晶 | 8 | 済 |
| ボタン 2 個 | 4 | 済 |
| カメラ 段階 1 | 7 | 済（PID 0x76 / VER 0x73 を確認） |
| カメラ 段階 2 | 11 | 済（取り込み成功） |
| 合計（完成時） | 34 | |

ジョイスティックを足す場合は +8（+V、GND×2、SW、A、B、C、D）で、タクトスイッチ 2 個の 4 本と入れ替わる。

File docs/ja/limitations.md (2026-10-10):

# 制約

この署名器が受け付けるもの、拒否するもの、実装していないものを説明します。バグと仕様上の境界を見分けられるようにまとめています。ここに記載した内容でも予想外の挙動があれば、[SECURITY.md](../../SECURITY.md) の手順で報告してください。

## 状態

第三者のレビューを受けておらず、signet でのみ確認しています。[README の安全上の注意](README.md#安全上の注意) もご覧ください。

## 取引

- **PSBT v0 のみ**（BIP174）に対応しています。v2 は拒否します。
- P2WPKH（BIP84）、P2TR key-path（BIP86）、**鍵3つまでの P2WSH マルチシグ**（BIP48、`m/48'/coin'/account'/2'`）に署名します。デバイスは共同署名者の鍵を持たないため、P2WSH の釣り銭は外部アドレスとして表示し、目で確認します。各共同署名者の PSBT は Core の wallet で結合します。P2WSH の入力が2件以上のときは、P2WPKH と同じく `non_witness_utxo` が必要です。
- **[BIP39](https://github.com/bitcoin/bips/blob/master/bip-0039.mediawiki) パスフレーズ入力**は今後対応予定ですが、現行ファームウェアでは使えません。共通 `signer.wasm` の ABI はパスフレーズを受け取れますが、Pico のファームウェアは空のパスフレーズで seed を導出します。
- 入力と出力はそれぞれ最大 **16 件**、PSBT は最大 **32,768 byte** です。
- scriptPubKey は最大 **83 byte** です（標準の OP_RETURN 上限です。P2TR と P2WSH は 34 byte です）。
- Taproot の script-path 支払い、miniscript、nLockTime の引き継ぎを超えるタイムロックには対応していません。
- 各入力には `witness_utxo` または `non_witness_utxo` が必要です。両方ある場合は、前トランザクションのハッシュが指定 txid と一致し、その出力が `witness_utxo` と一致することを確認します。
- 署名は**決定的**で、同じ PSBT から同じバイト列を生成します。[BIP340](https://github.com/bitcoin/bips/blob/master/bip-0340.mediawiki) の `aux_rand` は Bitcoin Core、Trezor、Jade、BDK と同じくゼロです。P2WSH マルチシグは共同署名者がそれぞれ ECDSA で署名するため影響を受けません。MuSig2 や FROST では決定的 nonce を使えないため、対応前に nonce 生成方式を見直す必要があります。

## 署名前にデバイスが確認すること

- デバイス自身で鍵を導出し、得られた scriptPubKey と PSBT の値を比較します。申告された導出パスだけは信用しません。
- デバイスで再導出して script が一致した場合に限り、出力を釣り銭と判定します。
- 検証済みの入力額と出力額から手数料を計算し、画面に表示します。
- 確認したものと同じ plan に対してのみ署名します。`core_sign` はレビュー済み plan の SHA-256 を再計算し、異なる場合は拒否します。

## 確認しないこと

- **送金先アドレスが意図した相手のものかは判定できません。** 別の経路で確認してください。
- 現在の手数料相場は分かりません。妥当に見える手数料でも誤っていることがあります。
- ブロックチェーンを参照しないため、入力が使用済みか、`non_witness_utxo` が実際に承認された取引かは判定できません。
- anti-exfil（sign-to-contract）は実装していません。悪意あるファームウェアが nonce に偏りを加える可能性があります。再現可能ビルドと画面上の parser hash で確認できる範囲に限られます。

## 鍵とメモリ

- シードは RAM のみに保持し、フラッシュには書きません。電源を入れ直した後は SeedQR を再度読み込む必要があります。
- ロック解除中は、署名に必要なマスター鍵と chain code も RAM にあります。**接続したデバッグプローブ（SWD）から読み取れる**ことを実測しています。[signing-architecture.md](../signing-architecture.md)（英語）をご覧ください。実際に使うときはプローブを外してください。
- `Lock (wipe seed)` は鍵をゼロ化します。前後の RAM ダンプで確認しています。
- mnemonic、BIP39 seed、SeedQR のペイロード、カメラ画像、導出した子鍵は使用後に消去します。署名 nonce も残りません。`tools/security/ram_keys.py` で確認しています。
- USB ブートローダー（BOOTSEL）に入ると SRAM 全体が消去されるため、残った鍵を読み出す経路にはなりません。
- 任意に電圧異常を起こしたりチップを調査したりできる攻撃者は防げません。署名前の署名検証と、署名セッションごとの secp256k1 コンテキスト再ランダム化で攻撃コストを上げますが、耐タンパー性を実現するものではありません。

## QR とデータ転送

- アニメーション QR は UR（BCR-2020-005）の fountain encoding を使います。各フレームを QR version 8 に収め、240x240 の画面をスマートフォンで読み取れるよう、断片を 100 byte にしています。
- 前トランザクションが大きい PSBT は収まらないことがあります。SegWit 入力の `non_witness_utxo` は `tools/psbt/strip_psbt.py` で削れます。faucet の入力に出力が 2,323 件ある場合、PSBT は 77KB、QR は 770 枚になりました。
- デバイスの QR デコーダ quirc は、QR が画面の大部分を占めないと読み取れません。離れた場所から画面を読む用途には向きません。
- QR デコーダは信頼境界ではありません。出力は解析器で解析し、再検証します。

## ハードウェア

- 対応する基板は Raspberry Pi Pico 2（RP2350、RISC-V Hazard3）のみです。他のターゲットでは検証していません。
- セキュアエレメント、改ざん検知、暗号化ストレージ、バックアップ電源付き RAM はありません。
- RP2350 のブート ROM はオープンソースではありません。
- `TEST_SEED=1` でビルドすると公開済みのテストシードを選べます。このビルドでは資金を扱わないでください。

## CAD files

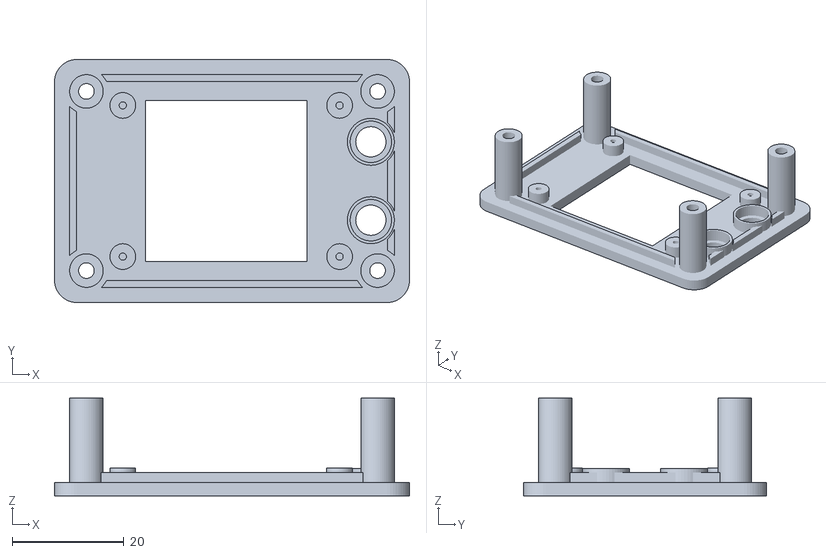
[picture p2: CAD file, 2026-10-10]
hardware/kicad/pico2h-carrier/3dprint/pico2h_case_front.stl
63.4 x 43.4 x 17.5

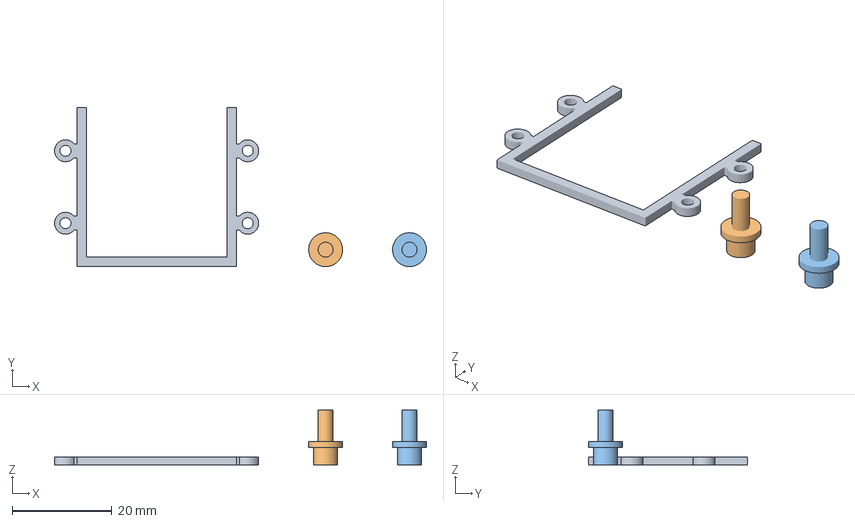
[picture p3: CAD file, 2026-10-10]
hardware/kicad/pico2h-carrier/3dprint/bambu_plate_03_small_parts.3mf
74.5 x 31.9 x 11.0 mm
camera_retainer
button_1
button_2

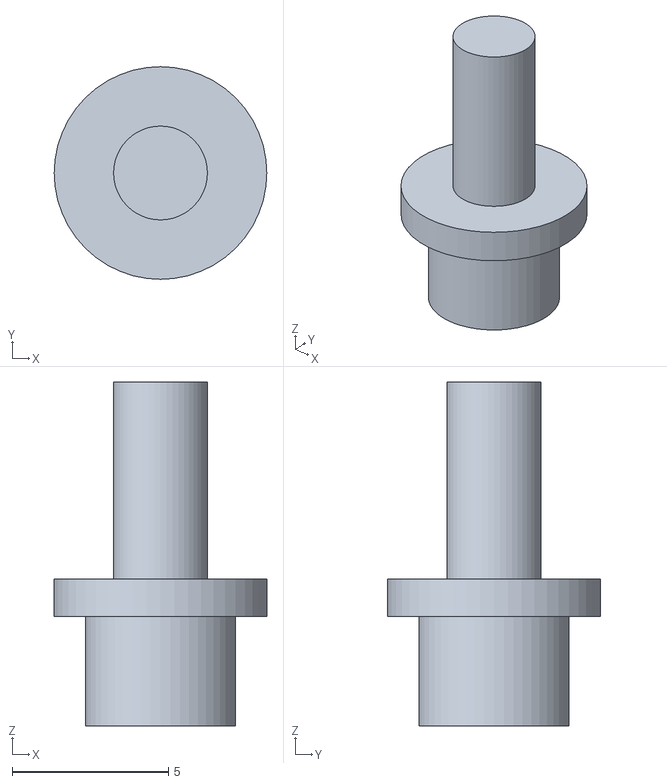
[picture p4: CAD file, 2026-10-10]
hardware/kicad/pico2h-carrier/3dprint/pico2h_case_button_2.stl
6.80 x 6.80 x 11.0

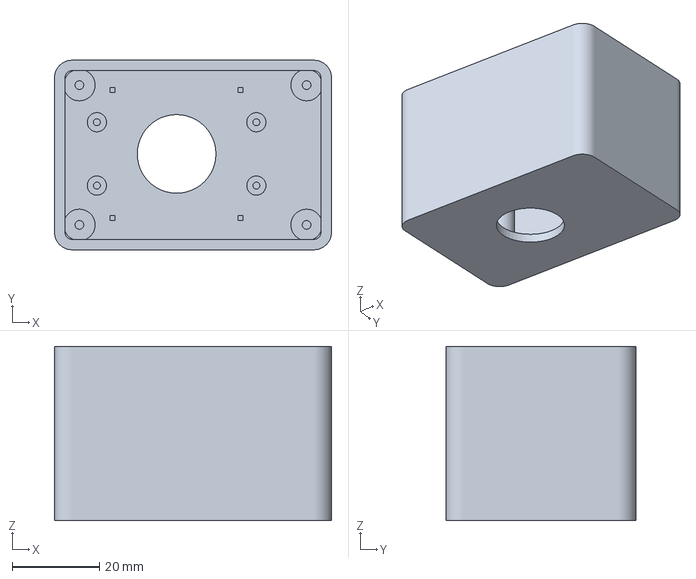
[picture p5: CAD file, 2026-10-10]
hardware/kicad/pico2h-carrier/3dprint/bambu_plate_01_base.3mf
63.4 x 43.4 x 39.9 mm

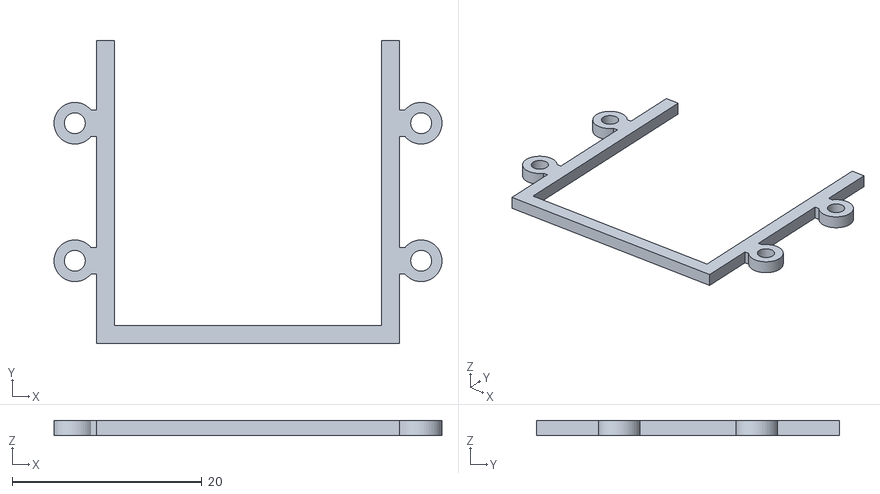
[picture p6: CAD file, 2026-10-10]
hardware/kicad/pico2h-carrier/3dprint/pico2h_case_camera_retainer.stl
40.9 x 31.9 x 1.60

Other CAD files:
hardware/kicad/pico2h-carrier/3dprint/pico2h_case_button_1.stl
hardware/kicad/pico2h-carrier/3dprint/bambu_plate_02_front.3mf
hardware/kicad/pico2h-carrier/3dprint/pico2h_case_base.stl
hardware/kicad/pico2h-carrier/3dprint/pico2h_case.scad

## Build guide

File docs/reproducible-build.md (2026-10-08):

# Reproducible builds

The device shows the SHA-256 of the `parser.wasm` it loaded. The point of this page is that anyone
can build that same file and get that same hash. Without it, "the device runs what you can read"
is a claim rather than something you can check.

## Using it

```sh
make check-repro
```

This downloads a toolchain pinned by version and hash into `build/toolchain/`, rebuilds the two
WASM artifacts used by this repository, and compares them against `checksums.txt`.

```
7c89bf15…  build/parser.wasm   the parser loaded by the device
96b78cd6…  build/signer.wasm   keys, derivation and signing, as a wasm component
```

## What is pinned

| | version | SHA-256 of the tarball |
|---|---|---|
| wasi-sdk | 34.0 | arm64-macos `9c593981…` / x86_64-linux `b761e3a0…` |
| binaryen (`wasm-opt`) | 132 | arm64-macos `98aad827…` / x86_64-linux `195ddc94…` |

`tools/build/toolchain.sh` fetches and verifies them. To add another platform, put its hash in the same place.

## What has been confirmed

**macOS arm64 and Linux x86_64 produce identical hashes.** Checked on a different OS, a different CPU
and a different machine (2026-10-03, and again on 2026-10-04 after adopting Lime1). CI rebuilds these
artifacts on Linux for every commit.

## The trap: `wasm-opt` merely being on the `PATH` changes the output

The first attempt gave 15,598 bytes on macOS and 18,278 on Linux, from the same wasi-sdk version.
The source, the compiler's default features, the sysroot's `libc.a` and the linker version were all
the same.

The cause is that **clang's driver silently runs `wasm-opt` afterwards if it finds one on the `PATH`.**
macOS had binaryen from Homebrew, so it ran; the Linux machine did not, so it did not.

```
clang ... -o out.wasm     ->  wasm-ld ... && /opt/homebrew/bin/wasm-opt out.wasm -Oz -o out.wasm
```

The fix is `--no-wasm-opt` to stop the driver doing it, then calling a pinned `wasm-opt` explicitly.
That needs **`-Wl,--keep-section=target_features`**: the driver only adds it when it is going to run
wasm-opt itself, and without it `--strip-all` removes `target_features`, after which the wasm-opt we
call cannot tell whether bulk memory is enabled and refuses to validate.

```make
WASM_OPT ?= wasm-opt
	$(LLVM)/clang ... --no-wasm-opt -Wl,--keep-section=target_features -o $@ $(SRC) -lc ...
	$(WASM_OPT) $@ -Oz -o $@
```

This is the worst kind of build bug — **the artifact depends on what happens to be installed** — and
comparing hashes is what surfaced it. It is also the reason to have reproducible builds at all.

## Pinning the wasm features to Lime1

[Lime1](https://github.com/WebAssembly/tool-conventions/blob/main/Lime.md) is a named level:
**WebAssembly 1.0 plus seven phase-5 (standardised) features.** Having defined it, the authors state
it will not change, so citing it does not drift.

```
-mcpu=lime1 -Xlinker --features=mutable-globals,multivalue,sign-ext,nontrapping-fptoint,bulk-memory-opt,extended-const,call-indirect-overlong
```

**Passing it to the linker is the point, because that makes it a gate.** The day a dependency tries to
bring in SIMD or threads, the link fails. What a runtime has to support can no longer widen quietly.

Everything got smaller as a side effect.

| | before | after |
|---|---:|---:|
| `parser.wasm` | 15,603 | **15,570** |
| `signer.wasm` | 56,508 | **56,475** |
| `bitcoin-signer.wasm` | 34,410 | **34,377** |

What validation demands narrowed too, from full `bulk-memory` to `bulk-memory-opt`.

**`-mcpu=mvp` does the opposite** and is not used: measured, it adds 2.5KB and still demands
`bulk-memory`. `-mcpu` only affects our own translation units, wasi-libc is already built with those
features, and `target_features` is the union of the inputs.

**`--no-growable-memory`** is used rather than `--max-memory=N`. The output is identical byte for byte,
and the limit cannot drift out of step with `--initial-memory`.

## Checking that what we ship has the right shape

```sh
make check-wasm     # needs wasm-tools (brew install wasm-tools)
```

The properties that let a user **check rather than trust** are worth checking continuously on our side
too.

| what | why |
|---|---|
| no imports | it cannot call a host function: no clock, no network |
| memory has a maximum | it cannot eat the host's memory through `memory.grow` |
| no mutable global exported | the host cannot reach in and rewrite internal state |
| no table exported | the indirect call table cannot be swapped out |
| no start function | loading it does not run anything |
| no unfamiliar custom sections | nothing extra came along |

The browser example and its auxiliary modules are maintained in
[jitsu-in](https://github.com/habakan/jitsu-in/tree/main/examples/viewer).

## Pinning the dependencies too

A pinned toolchain means nothing if the inputs move. Everything in `third_party/` is pinned to a commit
(`make check-deps`). In particular, **secp256k1 must not be taken from the tip of master**: that would
mean the library holding the keys varies by the day it was fetched.

| | |
|---|---|
| libsecp256k1 | pinned commit |
| WAMR | pinned upstream commit, including [PR #5123](https://github.com/wasm-micro-runtime/wasm-micro-runtime/pull/5123) |
| pico-sdk | commit matching a tag |
| quirc / QR-Code-generator / spleen | pinned commit |

Moving one means reading the diff, then changing the matching `*_REV` in the `Makefile`.

## The firmware

The released UF2s are built the same way, with the RISC-V toolchain pinned by hash in `make deps`:

```sh
make deps && ./tools/build/toolchain.sh && make check-repro
make build/rp2350/app.elf               # build/rp2350/app.uf2, mainnet
rm -rf build/rp2350 && make build/rp2350/app.elf TESTNET=1   # signet
```

macOS arm64 and Linux x86_64 give the same UF2, from different directories (2026-10-06). The one thing
that differed was the build date pico-sdk writes into the binary info, so the firmware turns it off
(`PICO_NO_BI_PROGRAM_BUILD_DATE=1`).

## Not done yet

- The toolchain comes from GitHub releases. Whether those tarballs are themselves reproducible is
  upstream's business

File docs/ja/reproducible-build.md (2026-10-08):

# 再現可能ビルド

デバイスは読み込んだ `parser.wasm` の SHA-256 を画面に表示します。このページでは、誰でも同じファイルをビルドし、同じハッシュを得る方法を説明します。再現できなければ、「デバイスは読めるソースコードと同じものを実行している」という主張を確かめられません。

## 実行

```sh
make check-repro
```

バージョンとハッシュを固定したツールチェーンを `build/toolchain/` に取得し、このリポジトリが使う WASM 成果物を2つビルドして、`checksums.txt` と照合します。

```
7c89bf15…  build/parser.wasm   デバイスが読み込む解析器
96b78cd6…  build/signer.wasm   鍵導出と署名を行う WASM コンポーネント
```

## 固定しているもの

| | バージョン | アーカイブの SHA-256 |
|---|---|---|
| wasi-sdk | 34.0 | arm64-macos `9c593981…` / x86_64-linux `b761e3a0…` |
| binaryen（`wasm-opt`） | 132 | arm64-macos `98aad827…` / x86_64-linux `195ddc94…` |

取得と検証は `tools/build/toolchain.sh` が行います。別のプラットフォームを追加するときは、同じスクリプトにハッシュを追加してください。

## 確認済みの環境

**macOS arm64 と Linux x86_64 で同じハッシュになります。** 別 OS、別 CPU、別マシンで確認しました（2026-10-03。Lime1 採用後の 2026-10-04 にも再確認しています）。CI は各コミットで Linux 上の再ビルドを行います。

## 注意点: `wasm-opt` が PATH にあるだけで成果物が変わる

最初の試行では、同じ wasi-sdk を使ったのに macOS で 15,598 byte、Linux で 18,278 byte になりました。ソース、コンパイラの既定機能、sysroot の `libc.a`、リンカのバージョンは同じでした。

原因は、clang のドライバが PATH 上の `wasm-opt` を見つけると、後から暗黙に実行することでした。Homebrew 版 Binaryen が入っていた macOS では実行され、Linux では実行されませんでした。

```sh
clang ... -o out.wasm     ->  wasm-ld ... && /opt/homebrew/bin/wasm-opt out.wasm -Oz -o out.wasm
```

`--no-wasm-opt` でドライバの自動実行を止め、固定した `wasm-opt` を明示的に呼びます。さらに `-Wl,--keep-section=target_features` が必要です。ドライバは自動で `wasm-opt` を実行するときだけこのセクションを残すため、指定しないと `--strip-all` が `target_features` を削除します。その後に呼ぶ `wasm-opt` は bulk memory が有効か判定できず、検証に失敗します。

```make
WASM_OPT ?= wasm-opt
	$(LLVM)/clang ... --no-wasm-opt -Wl,--keep-section=target_features -o $@ $(SRC) -lc ...
	$(WASM_OPT) $@ -Oz -o $@
```

インストール済みのツールに左右されるビルド不具合でした。ハッシュの比較で見つかりました。

## Lime1 による WASM 機能の固定

[Lime1](https://github.com/WebAssembly/tool-conventions/blob/main/Lime.md) は、WebAssembly 1.0 と7つの標準化済み phase-5 機能を定めた名前付きレベルです。仕様の作者は内容を変更しないとしています。

```sh
-mcpu=lime1 -Xlinker --features=mutable-globals,multivalue,sign-ext,nontrapping-fptoint,bulk-memory-opt,extended-const,call-indirect-overlong
```

リンカに指定することで、依存コードが SIMD やスレッドを持ち込んだ場合にリンクが失敗します。ランタイムが必要とする機能が知らないうちに増えるのを防ぎます。

| | 変更前 | 変更後 |
|---|---:|---:|
| `parser.wasm` | 15,603 | **15,570** |
| `signer.wasm` | 56,508 | **56,475** |
| `bitcoin-signer.wasm` | 34,410 | **34,377** |

検証に必要な機能も `bulk-memory` から `bulk-memory-opt` に絞られました。

`-mcpu=mvp` は逆の結果になるため使いません。測定では 2.5KB 増え、`bulk-memory` も引き続き必要でした。`-mcpu` が適用されるのは自プロジェクトの翻訳単位だけで、wasi-libc はすでに別の機能でビルドされています。`target_features` は入力の和集合になります。

`--max-memory=N` ではなく `--no-growable-memory` を使います。出力はバイト単位で同じで、メモリ上限が `--initial-memory` とずれることもありません。

## 配布物の形式を確認する

```sh
make check-wasm     # wasm-tools が必要です（brew install wasm-tools）
```

| 検査項目 | 理由 |
|---|---|
| import がない | ホスト関数（時計、ネットワークなど）を呼び出せない |
| memory に上限がある | `memory.grow` でホストのメモリを使い切れない |
| mutable global を export しない | ホストからモジュール内部の状態を書き換えられない |
| table を export しない | 間接呼び出しの table を差し替えられない |
| start function がない | 読み込み時にコードが実行されない |
| 未知の custom section がない | 余分なデータが追加されていない |

ブラウザの例と補助モジュールは [jitsu-in](https://github.com/habakan/jitsu-in/tree/main/examples/viewer) で管理しています。

## 依存関係も固定する

入力が変われば、ツールチェーンを固定しても意味がありません。`third_party/` の各依存はコミットに固定してあり、`make check-deps` で確認できます。特に **secp256k1 を master の先端から取得しないでください**。鍵を扱うライブラリの内容が取得日によって変わるためです。

| | 固定方法 |
|---|---|
| libsecp256k1 | コミット |
| WAMR | upstream の固定コミット（[PR #5123](https://github.com/wasm-micro-runtime/wasm-micro-runtime/pull/5123) を含む） |
| pico-sdk | タグに対応するコミット |
| quirc / QR-Code-generator / spleen | コミット |

依存を更新するときは差分を確認し、`Makefile` の対応する `*_REV` も更新してください。

## ファームウェア

リリース用 UF2 も同じ手順でビルドします。RISC-V ツールチェーンは `make deps` でハッシュを固定して取得します。

```sh
make deps && ./tools/build/toolchain.sh && make check-repro
make build/rp2350/app.elf               # build/rp2350/app.uf2、mainnet
rm -rf build/rp2350 && make build/rp2350/app.elf TESTNET=1   # signet
```

macOS arm64 と Linux x86_64 で、異なるビルドディレクトリから同じ UF2 を得ました（2026-10-06）。差が出たのは pico-sdk がバイナリ情報に書くビルド日だけだったため、ファームウェアでは `PICO_NO_BI_PROGRAM_BUILD_DATE=1` を指定しています。

## 未確認事項

- ツールチェーンは GitHub Releases から取得します。アーカイブ自体が再現可能にビルドされているかは確認していません。

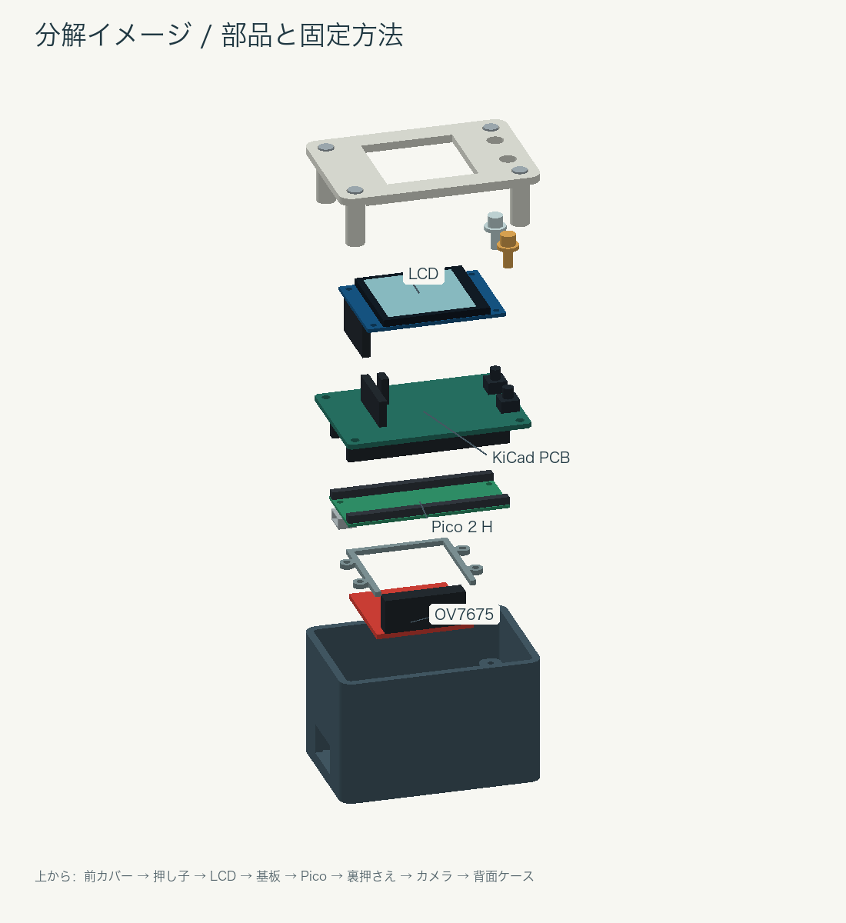
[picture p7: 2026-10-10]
hardware/kicad/pico2h-carrier/3dprint/assembly_exploded.png

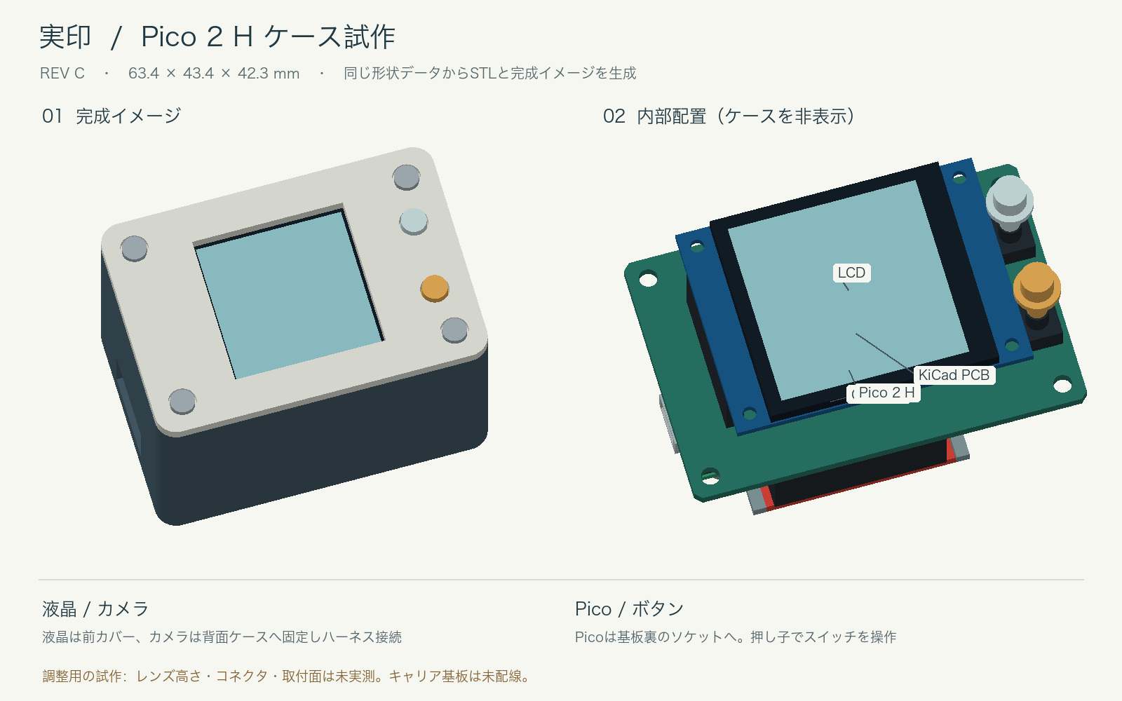
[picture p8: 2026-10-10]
hardware/kicad/pico2h-carrier/3dprint/assembly_preview.png

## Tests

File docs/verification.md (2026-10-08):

# Verification

This page groups the verification procedures for the device. The host and QEMU checks are listed in
the [README](../README.md#check-it-yourself); the process for rebuilding the pinned artifacts is in
[Reproducible builds](reproducible-build.md).

## Signet transaction

This end-to-end check signs and broadcasts a transaction on signet. The PC holds no private key or
seed phrase; the device signs the PSBT.

### Requirements

Install Bitcoin Core and run a signet node:

```sh
brew install bitcoin
mkdir -p "$HOME/Library/Application Support/Bitcoin"
printf 'signet=1\ndaemon=1\n' > "$HOME/Library/Application Support/Bitcoin/bitcoin.conf"
bitcoind
```

Allow substantial disk space for the chain. Do not prune the node: the wallet import below rescans
from `timestamp: 0`. If you use a remote node, keep its data directory on that machine's local disk;
do not mount it over SMB or NFS. Set up SSH forwarding and configure `~/.bitcoin-signet-rpc` with the
RPC command for your node. The helper's `tunnel` command is configured for development, so use your
own SSH tunnel for a different host.

### Procedure

1. Create a watch-only wallet from the descriptor shown by **Show xpub**. Replace the example
   descriptor with the one from the device:

   ```sh
   tools/device/watchonly.sh init 'wpkh([fingerprint/84h/1h/0h]tpub.../<0;1>/*)'
   ```

   The helper imports the receive (`/0/*`) and change (`/1/*`) branches separately, marks the latter
   as internal, and rescans from the beginning.

2. Get a receive address, fund it from a signet faucet, and check the balance:

   ```sh
   tools/device/watchonly.sh addr
   tools/device/watchonly.sh balance
   ```

3. Create a PSBT and the animated QR file to show to the device:

   ```sh
   tools/device/watchonly.sh send DESTINATION_ADDRESS 0.0005 1
   ```

   Replace `DESTINATION_ADDRESS` with the address to pay.

4. On the device, choose **Scan PSBT**, review the transaction, and approve it. Capture the signed
   UR from the UART log:

   ```sh
   make run SECONDS=300 2>&1 | tee /tmp/run.log
   ```

5. Finalize and broadcast the signed PSBT:

   ```sh
   tools/device/watchonly.sh broadcast /tmp/run.log
   ```

### Notes

- Faucet transactions can have more than 2,000 outputs. Including their full previous transactions
  can make a PSBT 77KB, or about 770 QR frames. `tools/psbt/strip_psbt.py` removes `non_witness_utxo` for
  SegWit inputs and reduces this example to about 339 bytes. This procedure uses single-signature
  P2WPKH; do not apply that shortcut to multisig.
- Import receive and change descriptors separately. Node versions differ in their handling of the
  multipath `<0;1>` form; swapping the branches can make `getnewaddress` return a change address.
- Use `timestamp: 0` so the wallet rescans for existing funds.
- For a remote node, SSH-forward its RPC port to local port 38332 and put a command like this in
  `~/.bitcoin-signet-rpc` (replace the credentials with the node's RPC credentials):

  ```sh
  CLI="bitcoin-cli -signet -rpcconnect=127.0.0.1 -rpcport=38332 -rpcuser=... -rpcpassword=..."
  ```

### Result

On 2026-10-03, the transaction
[`de849e8c…`](https://mempool.space/signet/tx/de849e8c01a39fcf2aa84aaeeccb2ac8aea128086b2f4252539bcab90a0a432f)
was broadcast without putting a private key or seed phrase on the PC. It was 141 vB with a fee of
141 sat.

| Check | Result |
|---|---|
| `core_account_xpub` output | Accepted by Bitcoin Core 31.1; matches embit |
| Change-address detection | Matches the device's ownership check |
| UR round trip | 4 parts sent; 32 returned; reconstructed after 5 parts in 553µs |
| Signature | ECDSA, P2WPKH, one input and two outputs |

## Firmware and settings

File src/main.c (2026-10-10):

/* The device application. The menu runs one signing round: read a PSBT, show every review screen,
 * and on approval sign it and hand the result back as an animated QR, then return to the menu.
 * The seed lives in RAM only while the power is on, and Lock clears it. Nothing is ever written to
 * flash. A TEST_SEED=1 build can load BIP39's test vector, and shows a warning screen for it; such a
 * build must never hold funds */
#include <stdio.h>
#include <stdlib.h>
#include <string.h>
#include "pico/stdlib.h"
#include "pico/rand.h"
#include "core.h"
#include "parser_host.h"
#include "sha256.h"
#include "sha512.h"
#include "wipe.h"
#include "ui.h"
#include "st7789.h"
#include "buttons.h"
#include "camera.h"
#include "quirc.h"
#include "seedqr.h"
#include "parser_wasm.h"
#include "test_psbt.h"

#define TEST_MNEMONIC "abandon abandon abandon abandon abandon abandon abandon abandon abandon abandon abandon about"

/* parser.wasm's linear memory comes out of this pool too, about 132KB with UR reassembly and
 * encoding. Measured at 149KB peak under QEMU */
static char pool[160 * 1024];
static uint8_t parser_wasm_rw[sizeof(parser_wasm)];
/* Not needed at the same time as quirc while reading (90KB, 77KB of it the image), so this is taken
 * from the heap only for the signing step */
#define SIGNED_PSBT_MAX (PARSER_PSBT_MAX + 2048)
static uint8_t *prevtx_arena, *signed_psbt, *psbt;
static int camera_ready;
static plan_t plan;
static ui_review_t review_ui;
static ui_menu_t menu;

/* With NO_LCD=1 the screens' text goes to the UART instead of the panel, which is how this was
 * checked before anything was soldered */
static void show(const ui_screen_t *s) {
    uint16_t line[UI_W];
#if NO_LCD
    printf("+--------------------------------+\n");
    for (int r = 0; r < UI_ROWS; r++)
        if (s->text[r][0]) printf("| %-30s |\n", s->text[r]);
    printf("+--------------------------------+\n");
    for (int y = 0; y < UI_H; y++) ui_render_line(s, y, line);
#else
    st7789_begin_frame();
    for (int y = 0; y < UI_H; y++) {
        ui_render_line(s, y, line);
        st7789_write_line(line);
    }
#endif
}

static int wait_key(void) {
    for (;;) {
        int key = buttons_poll();
        if (key >= 0) return key;
        sleep_ms(10);
    }
}

static void message(const char *title, const char *body, int warn) {
    static ui_screen_t s;
    ui_message(&s, title, body, warn);
    show(&s);
    printf("%s%s%s\n", title, body ? ": " : "", body ? body : "");
    wait_key();
}

/* The buffers the signing step uses, released on the way back to the menu because quirc takes the
 * same memory while reading */
static int sign_buffers_take(void) {
    prevtx_arena = malloc(PARSER_PSBT_MAX);
    signed_psbt = malloc(SIGNED_PSBT_MAX);
    return prevtx_arena && signed_psbt;
}

static void sign_buffers_give(void) {
    free(prevtx_arena);
    free(signed_psbt);
    prevtx_arena = signed_psbt = NULL;
}

/* Shows the captured frame, keeping a band at the top and bottom, with the status on the first line,
 * so the camera can actually be aimed */
static void show_preview(const uint8_t *img, const char *status) {
#if NO_LCD
    (void)img;
    printf("%s\n", status);
#else
    static ui_screen_t s;
    uint16_t line[UI_W];

    memset(&s, 0, sizeof(s));
    strncpy(s.text[0], status, UI_COLS);
    s.color[0] = 0xfd40;
    st7789_begin_frame();
    for (int y = 0; y < UI_H; y++) {
        if (y < 16) {
            ui_render_line(&s, y, line);
        } else if (y >= 30 && y < 210) { /* 320x240 decimated to three quarters, shown as 240x180 */
            int sy = (y - 30) * 4 / 3;
            for (int x = 0; x < UI_W; x++) {
                uint8_t v = img[sy * CAMERA_W + x * 4 / 3];
                line[x] = (uint16_t)((v >> 3) << 11 | (v >> 2) << 5 | (v >> 3));
            }
        } else {
            memset(line, 0, sizeof(line));
        }
        st7789_write_line(line);
    }
#endif
}

/* Reads an animated QR and reassembles the PSBT. Returns its length, or 0 if cancelled or failed */
static uint32_t scan_psbt(void) {
    struct quirc *q;
    unsigned parts = 0;
    uint64_t seen = 0; /* which parts have arrived, so a repeat is not counted twice */
    uint32_t len = 0;
    char status[UI_COLS + 1];

    if (!camera_ready) return message("No camera", "Wire it up or use the test PSBT.", 1), 0;
    if (!(psbt = malloc(PARSER_PSBT_MAX))) return message("Out of memory", NULL, 1), 0;
    if (!(q = quirc_new()) || quirc_resize(q, CAMERA_W, CAMERA_H) < 0) {
        free(psbt), psbt = NULL;
        return message("Out of memory", NULL, 1), 0;
    }
    parser_host_ur_reset();
    snprintf(status, sizeof(status), "Scan PSBT: aim at the QR");

    while (!len) {
        uint8_t *img = quirc_begin(q, NULL, NULL); /* captured straight into quirc's image buffer */
        int found = 0;
        if (buttons_poll() >= 0) break; /* any key cancels */
        if (!camera_capture(img, 500)) continue;
        show_preview(img, status);
        quirc_end(q);
        for (int i = 0; i < quirc_count(q) && !len; i++) {
            static struct quirc_code code;
            static struct quirc_data data;
            int32_t rc = 0;
            unsigned seq = 0, seq_len = 0;
            quirc_extract(q, i, &code);
            found = 1;
            if (quirc_decode(&code, &data)) {
                snprintf(status, sizeof(status), "QR found, cannot read");
                continue;
            }
            /* n and m out of "UR:CRYPTO-PSBT/<n>-<m>/", to show how many of how many */
            for (const char *c = (const char *)data.payload; *c; c++)
                if (*c == '/') {
                    while (*++c >= '0' && *c <= '9') seq = seq * 10 + (unsigned)(*c - '0');
                    if (*c == '-')
                        while (*++c >= '0' && *c <= '9') seq_len = seq_len * 10 + (unsigned)(*c - '0');
                    break;
                }
            if (!parser_host_ur_receive((const char *)data.payload, (uint32_t)data.payload_len, &rc, psbt,
                                        PARSER_PSBT_MAX)) {
                snprintf(status, sizeof(status), "QR read, not a PSBT");
                continue;
            }
            if (rc > 0) {
                len = (uint32_t)rc;
            } else if (rc == 0) {
                if (seq && seq <= 64 && !(seen >> (seq - 1) & 1)) seen |= (uint64_t)1 << (seq - 1), parts++;
                if (seq_len) snprintf(status, sizeof(status), "Scan PSBT  %u/%u parts", parts, seq_len);
                else snprintf(status, sizeof(status), "Scan PSBT  %u parts", parts);
            } else {
                snprintf(status, sizeof(status), "UR error %d", (int)rc);
            }
        }
        if (!found && parts == 0) snprintf(status, sizeof(status), "Scan PSBT: no QR in view");
    }
    quirc_destroy(q);
    if (!len) free(psbt), psbt = NULL;
    printf("scan: %u parts, psbt %u bytes\n", parts, (unsigned)len);
    return len;
}

static int trng(uint8_t *buf, size_t len) {
    /* pico_rand is seeded from the TRNG but is not a cryptographic PRNG. It is used only as Schnorr
     * aux data during the initial bring-up */
    for (size_t i = 0; i < len; i++) buf[i] = (uint8_t)get_rand_32();
    return 1;
}

static void draw_qr(void) {
    uint16_t line[UI_W];
#if NO_LCD
    for (int y = 0; y < UI_H; y++) ui_qr_render_line(y, line);
#else
    st7789_begin_frame();
    for (int y = 0; y < UI_H; y++) {
        ui_qr_render_line(y, line);
        st7789_write_line(line);
    }
#endif
}

/* Hands the signed PSBT back as an animated QR. Only pure parts are cycled, so a receiver that
 * cannot use mixed parts still completes, and a missed part comes round again. Any key ends it */
static void export_qr(uint32_t len) {
    long seq_len = parser_host_ur_encode_start(len, UI_UR_FRAGMENT);
    if (seq_len <= 0) return message("UR encode failed", NULL, 1);
    unsigned long part = 0;
    for (uint64_t next = 0;;) {
        static char text[1024];
        int key = buttons_poll();
        if (key == UI_KEY_UP || key == UI_KEY_DOWN) {
            ui_qr_level(key == UI_KEY_UP ? 1 : -1);
            printf("qr level %d\n", ui_qr_level_get());
            draw_qr();
        } else if (key >= 0) {
            return;
        }
        if (time_us_64() >= next) {
            if (part && part % (unsigned long)seq_len == 0) parser_host_ur_encode_start(len, UI_UR_FRAGMENT);
            if (!parser_host_ur_encode_next(text, sizeof(text)) || !ui_qr_set(text))
                return message("QR failed", NULL, 1);
            part++;
            /* also on the UART, for when the camera cannot read the screen */
            printf("%s\n", text);
            draw_qr();
            /* at 250ms a phone changes part before it has focused, and parts get missed */
            next = time_us_64() + 500 * 1000;
        }
        sleep_ms(10);
    }
}

/* Signs one PSBT and returns to the menu. psbt and psbt_len are what was read */
static void sign_flow(const uint8_t *in, uint32_t in_len) {
    core_prevtx_t prev[PLAN_MAX_INPUTS];
    core_review_t review;
    core_display_t display;
    core_sig_t sigs[PLAN_MAX_INPUTS];
    uint32_t rc = 0, out_len = 0;
    unsigned n_sigs = 0;
    uint64_t t;
    int err, decision = UI_PENDING;

    if (!sign_buffers_take()) return sign_buffers_give(), message("Out of memory", NULL, 1);

    t = time_us_64();
    if (!parser_host_parse(in, in_len, core_fingerprint(), &rc, &plan, prev, prevtx_arena, PARSER_PSBT_MAX) || rc) {
        printf("parse failed rc=%u\n", (unsigned)rc);
        return sign_buffers_give(), message("Invalid PSBT", NULL, 1);
    }
    printf("parse %llu us, pool highmark %u\n", (unsigned long long)(time_us_64() - t),
           (unsigned)parser_host_pool_highmark());

    t = time_us_64();
    if ((err = core_review(&plan, prev, &review)) != CORE_OK ||
        (err = core_display(&plan, &review, &display)) != CORE_OK) {
        printf("review err=%d\n", err);
        return sign_buffers_give(), message("Rejected by review", NULL, 1);
    }
    printf("review %llu us\n", (unsigned long long)(time_us_64() - t));

    ui_review_init(&review_ui, &display);
    show(&review_ui.screens[0]);
    while (decision == UI_PENDING) {
        int key = buttons_poll();
        if (key >= 0) {
            unsigned before = review_ui.cur;
            decision = ui_review_key(&review_ui, key);
            if (review_ui.cur != before) show(&review_ui.screens[review_ui.cur]);
        }
        sleep_ms(10);
    }
    if (decision == UI_REJECTED) return sign_buffers_give(), message("Canceled", NULL, 0);

    t = time_us_64();
    if ((err = core_sign(&plan, trng, sigs, &n_sigs)) != CORE_OK) {
        printf("sign err=%d\n", err);
        return sign_buffers_give(), message("Sign failed", NULL, 1);
    }
    printf("sign %llu us (%u inputs)\n", (unsigned long long)(time_us_64() - t), n_sigs);
    if (!parser_host_finalize(sigs, n_sigs, signed_psbt, SIGNED_PSBT_MAX, &out_len))
        return sign_buffers_give(), message("Finalize failed", NULL, 1);

    printf("signed psbt (%u bytes):\n", (unsigned)out_len);
    for (uint32_t i = 0; i < out_len; i++) printf("%02x%s", signed_psbt[i], (i % 32 == 31) ? "\n" : "");
    printf("\n");
    export_qr(out_len);
    sign_buffers_give();
}

static void scan_and_sign(void) {
    uint32_t len = scan_psbt();
    if (!len) return;
    sign_flow(psbt, len);
    free(psbt), psbt = NULL;
}

/* Reads a SeedQR and loads the seed. It is the secret itself, so it is handled here and never goes
 * through the parser */
static int scan_seed(void) {
    struct quirc *q;
    char status[UI_COLS + 1], mnemonic[256];
    uint8_t seed[64];
    /* The payload is the seed. Too large for the stack, so it is static and wiped at the end */
    static struct quirc_code code;
    static struct quirc_data data;
    int ok = 0;

    if (!camera_ready) return message("No camera", "Wire it up or use the test seed.", 1), 0;
    if (!(q = quirc_new()) || quirc_resize(q, CAMERA_W, CAMERA_H) < 0) return message("Out of memory", NULL, 1), 0;
    snprintf(status, sizeof(status), "Scan SeedQR");

    while (!ok) {
        uint8_t *img = quirc_begin(q, NULL, NULL);
        if (buttons_poll() >= 0) break;
        if (!camera_capture(img, 500)) continue;
        show_preview(img, status);
        quirc_end(q);
        for (int i = 0; i < quirc_count(q) && !ok; i++) {
            quirc_extract(q, i, &code);
            if (quirc_decode(&code, &data)) {
                snprintf(status, sizeof(status), "QR found, cannot read");
                continue;
            }
            if (!seedqr_decode(data.payload, (size_t)data.payload_len, mnemonic, sizeof(mnemonic))) {
                snprintf(status, sizeof(status), "Not a valid SeedQR");
                continue;
            }
            pbkdf2_hmac_sha512((const uint8_t *)mnemonic, strlen(mnemonic), (const uint8_t *)"mnemonic", 8, 2048, seed);
            ok = core_load_seed(seed);
        }
    }
    /* The captured frame still holds the SeedQR, readable over SWD, so it is wiped before release */
    wipe(quirc_begin(q, NULL, NULL), (size_t)CAMERA_W * CAMERA_H);
    quirc_destroy(q);
    wipe(&code, sizeof(code));
    wipe(&data, sizeof(data));
    wipe(mnemonic, sizeof(mnemonic));
    wipe(seed, sizeof(seed));
    if (ok) printf("seed from SeedQR, fingerprint %08x\n", (unsigned)core_fingerprint());
    return ok;
}

#if TEST_SEED
static int load_test_seed(void) {
    uint8_t seed[64];
    uint64_t t;
    int ok;

    message("TEST SEED", "Public BIP39 vector. Never send funds to this wallet.", 1);
    t = time_us_64();
    pbkdf2_hmac_sha512((const uint8_t *)TEST_MNEMONIC, sizeof(TEST_MNEMONIC) - 1, (const uint8_t *)"mnemonic", 8, 2048,
                       seed);
    ok = core_load_seed(seed);
    memset(seed, 0, sizeof(seed));
    printf("seed %llu us, fingerprint %08x\n", (unsigned long long)(time_us_64() - t), (unsigned)core_fingerprint());
    return ok;
}
#endif

static void seed_menu(void) {
    static const char *const items[] = {"Scan SeedQR", "Use test seed"};
    int sel;

    ui_menu_init(&menu, "No seed loaded", items, TEST_SEED ? 2 : 1);
    show(&menu.screen);
    for (;;) {
        sel = ui_menu_key(&menu, wait_key());
        if (sel == UI_MENU_PENDING) {
            show(&menu.screen);
            continue;
        }
        if (sel == 0) {
            if (scan_seed()) return;
            show(&menu.screen);
            continue;
        }
#if TEST_SEED
        if (sel == 1 && load_test_seed()) return;
#endif
        show(&menu.screen);
    }
}

/* Shows the account xpub and descriptor. That is all the PC needs to watch the wallet, with no key. For
 * purpose 48 the descriptor is this cosigner's key expression, which the PC puts into wsh(sortedmulti()) */
static void show_xpub(unsigned purpose) {
    static ui_screen_t s;
    static char xpub[CORE_XPUB_MAX], desc[CORE_DESC_MAX];

    if (core_account_xpub(purpose, 0, xpub, desc) != CORE_OK) return message("xpub failed", NULL, 1);
    ui_xpub(&s, xpub, core_fingerprint(), TESTNET, purpose);
    show(&s);
    printf("%s\n%s\n", xpub, desc);
    wait_key();

    /* The descriptor runs to about 145 characters, which fits QR v8, so one still image carries it */
    if (!ui_qr_set(desc)) return message("QR failed", NULL, 1);
    printf("descriptor QR: %d modules\n", ui_qr_modules());
    for (;;) {
        int key;
        draw_qr();
        key = wait_key();
        if (key != UI_KEY_UP && key != UI_KEY_DOWN) return;
        ui_qr_level(key == UI_KEY_UP ? 1 : -1);
        printf("qr level %d\n", ui_qr_level_get());
    }
}

/* The hash of the parser.wasm actually loaded. Matching it against the jitsu-in viewer is
 * how you confirm the device is running the same module you are */
static void show_parser_hash(void) {
    static ui_screen_t s;
    uint8_t h[32];

    sha256(parser_wasm, sizeof(parser_wasm), h);
    ui_hash(&s, "parser.wasm", (unsigned)sizeof(parser_wasm), h);
    show(&s);
    printf("parser.wasm %u B sha256 ", (unsigned)sizeof(parser_wasm));
    for (int i = 0; i < 32; i++) printf("%02x", h[i]);
    printf("\n");
    wait_key();
}

static void main_menu(void) {
    static const char *const items[] = {"Scan PSBT",   "Show xpub",      "Show multisig xpub",
                                        "Parser hash", "Sign test PSBT", "Lock (wipe seed)"};
    static const char *const items_notest[] = {"Scan PSBT", "Show xpub", "Show multisig xpub", "Parser hash",
                                               "Lock (wipe seed)"};
    static char title[UI_COLS + 1];

    snprintf(title, sizeof(title), "%s fp %08x", TESTNET ? "Signet" : "Signer", (unsigned)core_fingerprint());
    ui_menu_init(&menu, title, TEST_SEED ? items : items_notest, TEST_SEED ? 6 : 5);
    show(&menu.screen);
    for (;;) {
        int sel = ui_menu_key(&menu, wait_key());
        if (sel == 0) scan_and_sign();
        if (sel == 1) show_xpub(84);
        if (sel == 2) show_xpub(48);
        if (sel == 3) show_parser_hash();
#if TEST_SEED
        if (sel == 4) sign_flow(test_psbt, sizeof(test_psbt));
#endif
        if (sel == (TEST_SEED ? 5 : 4)) {
            core_unload();
            printf("locked (seed wiped)\n");
            return;
        }
        show(&menu.screen);
    }
}

int main(void) {
    stdio_init_all();
#if !NO_LCD
    st7789_init();
#endif
    buttons_init();
    printf("\njitsu-in-pico (%s)\n", TESTNET ? "testnet/signet" : "mainnet");

    memcpy(parser_wasm_rw, parser_wasm, sizeof(parser_wasm_rw));
    /* A TESTNET=1 build targets signet and testnet: tb1 addresses, derived under m/84'/1'/... */
    if (!core_init(TESTNET ? CORE_TESTNET : CORE_MAINNET) ||
        !parser_host_init(parser_wasm_rw, sizeof(parser_wasm_rw), pool, sizeof(pool))) {
        message("Init failed", NULL, 1);
        return 1;
    }
    camera_bus_init(&camera_ov7670);
    camera_ready = camera_init(&camera_ov7670);
    printf("camera: %s\n", camera_ready ? "ready" : "not connected");
    for (;;) {
        seed_menu();
        main_menu();
    }
}

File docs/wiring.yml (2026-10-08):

# 実配線の定義。WireViz で図と部品表にする: make wiring
#
# ブレッドボードの行と穴は docs/breadboard.md を見る。ここでは「どの部品のどのピンが、
# どの信号で、どこに繋がっているか」だけを持つ。配線を変えたらここと breadboard.md の両方を直す。

connectors:
  Pico:
    pinlabels:
      - GP0 (UART TX)
      - GP2 (cam D0)
      - GP3 (cam D1)
      - GP4 (cam D2)
      - GP5 (cam D3)
      - GP6 (cam D4)
      - GP7 (cam D5)
      - GP8 (cam D6)
      - GP9 (cam D7)
      - GP10 (cam PCLK)
      - GP11 (cam HREF)
      - GP12 (cam VSYNC)
      - GP14 (cam SDA)
      - GP15 (cam SCL)
      - GP16 (lcd DC)
      - GP17 (btn next)
      - GP18 (lcd SCL)
      - GP19 (lcd SDA)
      - GP21 (cam XCLK)
      - GP26 (btn ok)
      - 3V3 OUT
      - GND
    notes: Raspberry Pi Pico 2 H。C 列と H 列の行 1〜20

  LCD:
    pinlabels: [GND, VCC, SCL, SDA, RES, DC, CS, BLK]
    notes: M154-240240-RGB (ST7789V)。行 36〜43 の J 列

  Camera:
    pinlabels: [VCC, GND, SCL, SDA, VS, HS, PCLK, XCLK, D7, D6, D5, D4, D3, D2, D1, D0, PEN, PDN]
    notes: OV7675 (Arducam B0070)。オス-メス線でぶら下げる

  SW1:
    pinlabels: [A, B]
    notes: タクトスイッチ（進む）。行 24 / 26
  SW2:
    pinlabels: [A, B]
    notes: タクトスイッチ（承認）。行 28 / 30

  Rail3V3:
    pinlabels: [row42, row45, row47]
    notes: A 列外側の赤レール。Pico の 3V3 を液晶の行 42 から引く
  RailGND:
    pinlabels: [row9, row10, row13]
    notes: A 列外側の青レール。Pico の GND（B13）から引く

  Probe:
    pinlabels: [U-RX, U-GND, D-SWD]
    notes: Raspberry Pi Debug Probe。U は UART、D は SWD

cables:
  rail_3v3: {colors: [RD]}
  rail_gnd: {colors: [BK]}
  lcd_pwr: {colors: [RD, BK]}
  lcd_spi: {colors: [YE, GN, BU]}
  cam_vcc: {colors: [RD]}
  cam_pen: {colors: [RD]}
  cam_gnd: {colors: [BK]}
  cam_pdn: {colors: [BK]}
  cam_i2c: {colors: [YE, GN, WH]}
  cam_data: {colors: [BN, RD, OG, YE, GN, BU, VT, GY, WH, PK, TQ]}
  sw1: {colors: [WH, BK]}
  sw2: {colors: [WH, BK]}
  uart: {colors: [WH, BK]}

connections:
  # 電源レール（Pico から引き込む）
  - - Pico: [3V3 OUT]
    - rail_3v3: [1]
    - Rail3V3: [row42]
  - - Pico: [GND]
    - rail_gnd: [1]
    - RailGND: [row13]

  # 液晶。RES と BLK は基板上の行で VCC と、CS は GND と同じ（図では 1 本にまとめている）
  - - Pico: [3V3 OUT, GND]
    - lcd_pwr: [1, 2]
    - LCD: [VCC, GND]
  - - Pico: [GP18 (lcd SCL), GP19 (lcd SDA), GP16 (lcd DC)]
    - lcd_spi: [1, 2, 3]
    - LCD: [SCL, SDA, DC]

  # カメラの電源はレールから取る
  - - Rail3V3: [row45]
    - cam_vcc: [1]
    - Camera: [VCC]
  - - Rail3V3: [row47]
    - cam_pen: [1]
    - Camera: [PEN]
  - - RailGND: [row9]
    - cam_gnd: [1]
    - Camera: [GND]
  - - RailGND: [row10]
    - cam_pdn: [1]
    - Camera: [PDN]

  # カメラの信号
  - - Pico: [GP15 (cam SCL), GP14 (cam SDA), GP21 (cam XCLK)]
    - cam_i2c: [1, 2, 3]
    - Camera: [SCL, SDA, XCLK]
  - - Pico: [GP2 (cam D0), GP3 (cam D1), GP4 (cam D2), GP5 (cam D3), GP6 (cam D4), GP7 (cam D5),
             GP8 (cam D6), GP9 (cam D7), GP10 (cam PCLK), GP11 (cam HREF), GP12 (cam VSYNC)]
    - cam_data: [1, 2, 3, 4, 5, 6, 7, 8, 9, 10, 11]
    - Camera: [D0, D1, D2, D3, D4, D5, D6, D7, PCLK, HS, VS]

  # ボタン（片側を GND、もう片側を GPIO へ）
  - - Pico: [GP17 (btn next), GND]
    - sw1: [1, 2]
    - SW1: [B, A]
  - - Pico: [GP26 (btn ok), GND]
    - sw2: [1, 2]
    - SW2: [B, A]

  # Debug Probe（SWD の 3 ピンケーブルは別系統なので図に出さない）
  - - Pico: [GP0 (UART TX), GND]
    - uart: [1, 2]
    - Probe: [U-RX, U-GND]

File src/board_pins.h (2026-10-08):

#ifndef BOARD_PINS_H
#define BOARD_PINS_H

/* The GPIO assignment from docs/hardware.md; change both together */

#define PIN_UART_TX 0 /* to the Debug Probe's UART; RX is unused */

#define PIN_CAM_D0 2 /* D0 to D7 are read as a run by PIO, so they sit on GP2 to GP9 */
#define PIN_CAM_PCLK 10
#define PIN_CAM_HREF 11
#define PIN_CAM_VSYNC 12
#define PIN_CAM_SIOD 14 /* I2C1 SDA */
#define PIN_CAM_SIOC 15 /* I2C1 SCL */
#define PIN_CAM_XCLK 21 /* CLOCK GPOUT0; unused on an OV2640 board that has its own crystal */

#define PIN_LCD_DC 16
#define PIN_LCD_SCK 18  /* SPI0 SCK */
#define PIN_LCD_MOSI 19 /* SPI0 TX; CS is tied to ground, RES and BLK to 3V3 */

#define PIN_JOY_UP 13
#define PIN_JOY_DOWN 17
#define PIN_JOY_LEFT 20
#define PIN_JOY_RIGHT 22
#define PIN_JOY_PUSH 26
#define PIN_BTN_A 27
#define PIN_BTN_B 28
#define PIN_BTN_C 1

#endif

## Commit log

2026-10-09 fix: build against jitsu-in main: its word list, xpub API, BIP85 and message signing
    The parts now need seedqr.c and bip85.c beside core.c, and secp256k1's recovery module.
    [main.c]
2026-10-10 feat: sign P2WSH multisig and show the BIP48 cosigner key
    Brings in the parts commit that lets the Pico act as one cosigner of a 2-of-3.
2026-10-10 feat: Pico 2 H用キャリア基板のKiCad下書きを追加
    ブレッドボード配線を基板へ移し、ケース設計に進むため
    [pico2h_carrier.kicad_pcb, pico2h_carrier.kicad_sch]
2026-10-10 feat: Pico 2 Hケースの3Dプリント用STLを追加
    基板と周辺部品をケースに収めて配線を保護するため
    [pico2h_case.scad, pico2h_case_base.stl, pico2h_case_front.stl]
2026-10-10 feat: Pico 2 Hケースを58x38 mm基板・背面カメラのRev Cへ変更
    基板を小さくし、カメラを背面へ移したうえで、印刷できる区切りの形状を残すため。
    [bambu_plate_01_base.3mf, bambu_plate_02_front.3mf, bambu_plate_03_small_parts.3mf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]
